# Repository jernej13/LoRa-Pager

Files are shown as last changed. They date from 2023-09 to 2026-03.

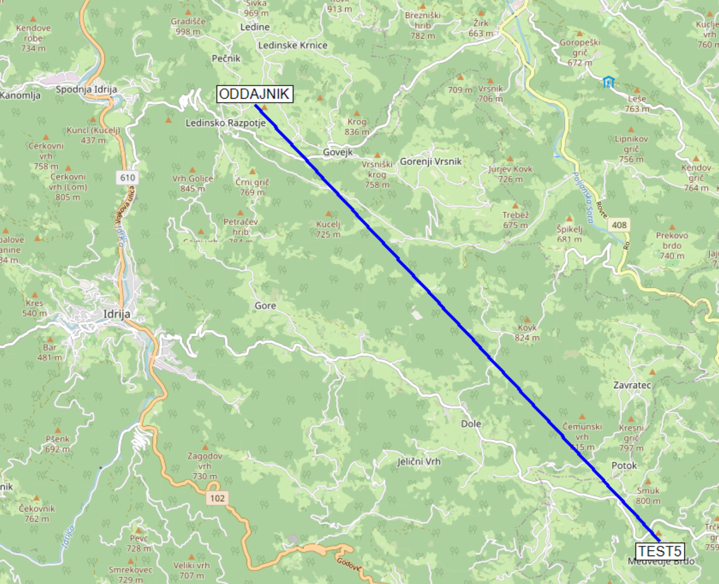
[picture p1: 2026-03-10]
tests/TEST5/map pic.png

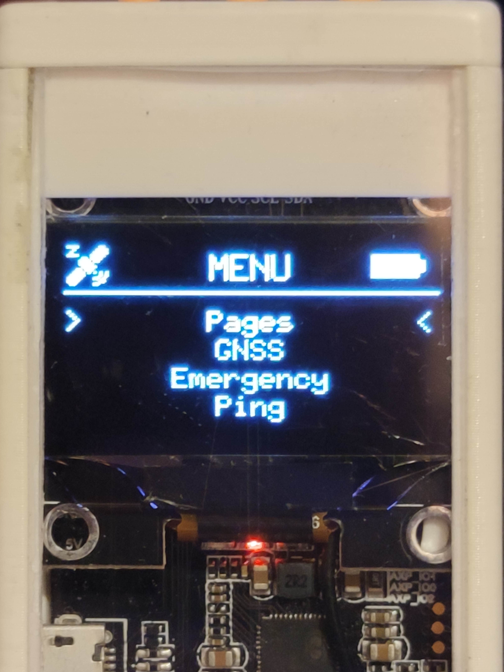
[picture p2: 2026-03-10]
pictures/IMG_20230325_204728.jpg

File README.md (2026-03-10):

# LoRa Pager (ESP32)

This repository contains my **high school graduation project (Slovenian *matura*)**, where I designed and built a **portable LoRa-based communication device** capable of long-range peer-to-peer messaging without relying on existing network infrastructure.

The device is built around an **ESP32 microcontroller** and uses **LoRa radio communication** to send predefined messages between devices over long distances.

The project includes **hardware design, embedded firmware, and a 3D printed enclosure**.

<p align="center">
  
</p>

---

## Features

* Long-range **LoRa peer-to-peer communication**
* **GNSS location support**
* **OLED graphical interface**
* Menu-based navigation with buttons
* **Emergency beacon mode**
* Battery monitoring and low-power operation
* Custom **3D printed enclosure**

---

## Hardware

Main components:

* ESP32 microcontroller
* Semtech **SX1276 LoRa transceiver**
* **U-blox NEO-M8N GNSS module**
* 128×64 **OLED display**
* Buttons and piezo buzzer
* Li-ion battery with power management

Development board used:

* **LilyGO TTGO T-Beam V1.1**

---

## Software

The firmware is written in **C++ using the Arduino framework** and developed with **PlatformIO**.

The program manages:

* LoRa communication
* GNSS data processing
* graphical user interface
* power management

---

## Results

Field tests achieved communication distances of **over 9 km** using LoRa with a transmission power of **0.1 W**.

---

## Author

**Jernej Leskovec**
High School Graduation Project (*Matura*)
Ljubljana, Slovenia

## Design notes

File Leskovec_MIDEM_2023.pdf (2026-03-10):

# LoRa Pager – Portable Off-Grid Communication

### Jernej Leskovec, Janez Omahen

The Upper Secondary School of Electrical and Computer Engineering
and Technical Gymnasium Ljubljana, Slovenia
jernej.leskovec13@gmail.com, janez.omahen@vegova.si

Abstract − This paper describes the selected parts, functionalities, and performance results of the LoRa pager prototype. LoRa pager is an off-grid peer-to-peer communicator that takes advantage of LoRa technology. The LoRa pager also uses the GNSS (global navigation satellite system) positioning to determine and send location.

### 1 INTRODUCTION

In our modern world, we increasingly rely on many different types of networks (cellular networks, internet). These come with trivial advantages, for example, high bitrates, good coverage, seamless connection, and low power consumption on the user end. But it also comes with some disadvantages: networks are localized and fragile. Even a power outage can lead a city or a whole region to lose modern communication with the rest of the world. In the case of a natural catastrophe, for example, a flood, the most
affected | parts | can | lose | all | network-related
connections. The only exceptions are radio amateurs who have expensive equipment and receive training. We wanted a more subtle, pocketable, and cheaper way of communicating long distances.

### 2 PARTS SELECTION

Searching the internet, we came across LoRa. LoRa is a somewhat new technology. It’s a way of communication using spread spectrum modulations, a branch of CSS (Chirp spread spectrum) technology. LoRa uses an open ISM (Industrial, scientific, medical) frequency band. There is no license needed for transmitting on 433 MHz (ISM) in Europe (that being if the transmission is using less than 25 mW of power) [1]. Next, we needed a microcontroller. ESP32 fits all the needs and is widely available. For the user interface, we decided on a small OLED screen with three buttons and a piezo speaker to go with it.

### 3 FUNCTIONALITY

The pager functions in a way that it sends integers instead of strings of data over the air, and every integer has a pre-programmed text to go with it. We choose a page in the menu, and when we send it, the LoRa module only sends the integer that belongs to that page. Next, the receiving LoRa module receives that integer, and the text allocated to that integer gets displayed on the display of the receiving pager. The advantages of this type of communication are lower battery consumption since we need less time to send that two-byte integer than the dozen-byte string packet, ease of use, and the unnecessity of a functional text input method. But this design also poses a couple of drawbacks, one of which is that we only have a selected number of pages to send, thus limiting the information we can tell.

### 3.1 User Interface

With such a small form factor and the lack of buttons to navigate the user interface, we have programmed the pagers to have a selection menu. We can navigate different options for the pager’s functionality in a menu. The menu has a layered setup, as seen in Figures 1 and 2.

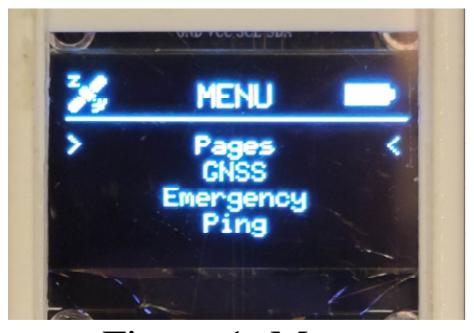
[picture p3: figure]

### 3.2 GNSS

The pager has a GNSS receiver since geolocation is practical in dire situations (Figure 3). We can send or receive the location from one pager to another. The pagers can also act as an emergency beacon, sending the position with an emergency page every 10 seconds (Figure 4).

Figure 1: Menu | Figure 2: Pages
Figure 3: GNSS Info | Figure 4: Receiving Emergency

### 4 HOUSING

The housing was 3D designed and 3D printed. It consists of 4 parts. The most significant is the main body, which has a hole for the USB micro connector. The bottom and the top part, the latter of which has four holes, three for buttons and the fourth one for the antenna. The fourth part is an acrylic glass that covers the front. The bottom and top were both screwed into place while the acrylic got glued (Figure 5).

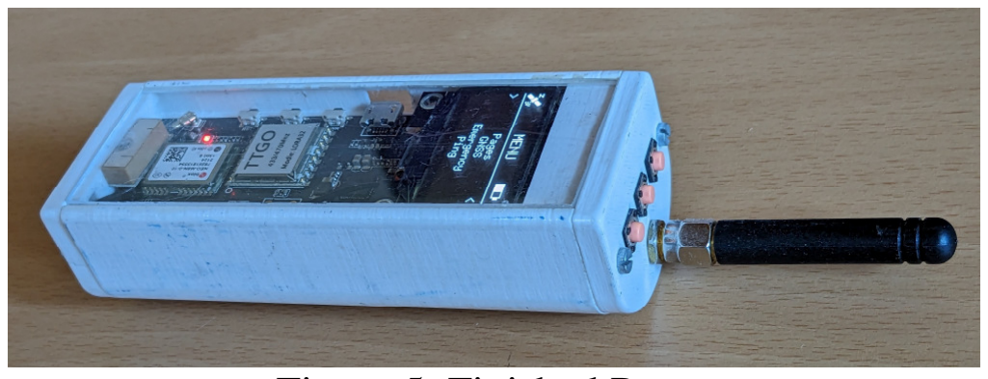
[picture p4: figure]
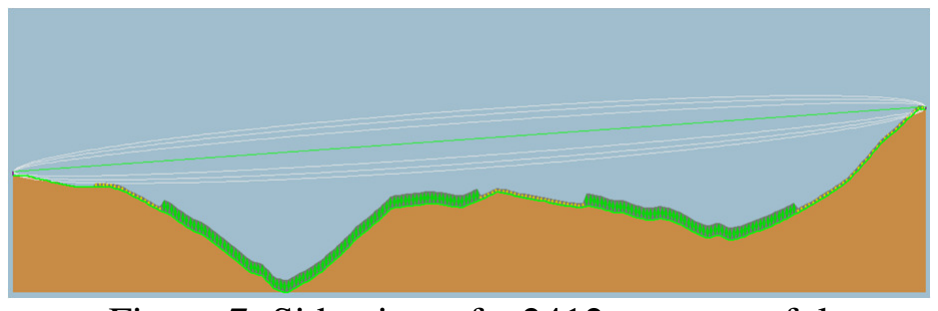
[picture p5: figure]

### 5 EXPECTATIONS

The world record for the LoRa transmission using 25 mW of power is 832 kilometers [2]. With that in mind, we were expecting a lot. Since 433 MHz is a high frequency and is very limited to the field of view, we expected our pagers would not work around big obstacles, such as hills or mountains.

### 6 RESULTS

We started testing the pagers with only the test code that pings one another. And at the beginning, the pagers were getting less than a hundred meters of range. The range increased after changing and calculating the best possible setting for LoRa. Testing the transmission range of the LoRa pagers if there is an obstacle in the way of the line of sight, has proven poorly. We had a transmitter that transmitted every 10 seconds about 200 meters away and 40 meters lower altitude from where we were standing on a small hill. The side facing the transmitter had reception, but we lost reception when we moved with our receiver just a few meters lower to the opposite side of the hill. After finishing the code for the pagers, we tested the range.

### 6.1 Short Distance

Short distance (~100m to ~2000m) line of sight pagers have no problem receiving. Signal strength (RSSI) ranges between -110 and -120 dBm. Trees, houses, and other small obstacles do not impact the signal strength.

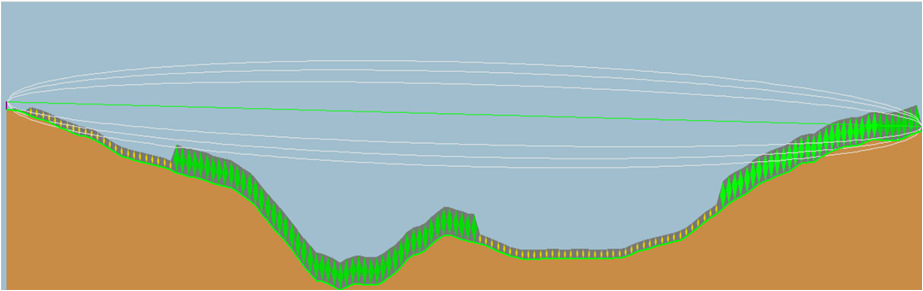
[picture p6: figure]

### 6.2 Long Distance

At longer distances (~2000m+) in line of sight, pagers have no problem receiving. RSSI is on the edge of pager capabilities, between -120 and -135 dBm. The estimated RSSI is -148 dBm [3], which is lower than what we managed to get, even when we barely received it. That RSSI would only be possible with the smallest bandwidth, but our pagers cannot handle anything below 62.5 kHz.

Figure 5: Finished Pager

Figure 6: Side view of a 1509m successful transmission (RSSI -116)

Figure 7: Side view of a 2412 m successful transmission (RSSI -114)

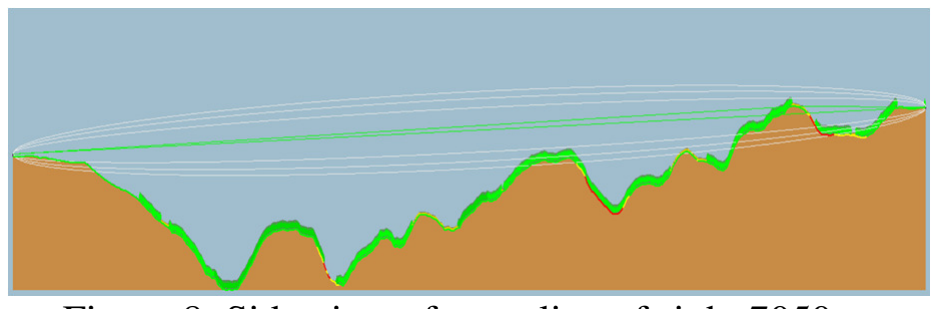
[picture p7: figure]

Figure 8: Side view of a not line of sight 7050 m successful transmission (RSSI -131)

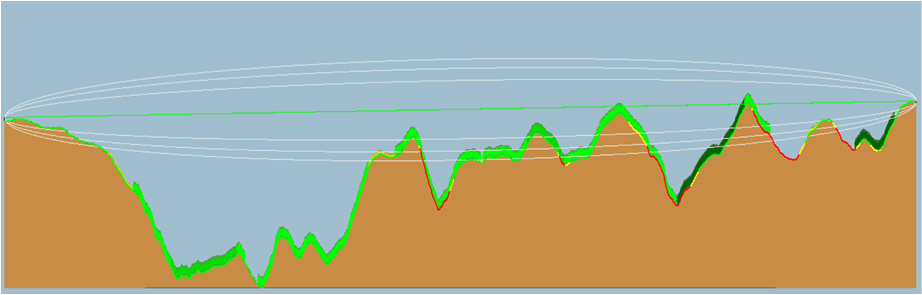
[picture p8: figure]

Figure 9: Side view of a 9231 m successful transmission (RSSI -132)

### 7 CONCLUSIONS

To sum up, we have built a portable, easy-to-use, and well-preforming off-grid communicator. The pagers have some advantages. For example, they can receive
through | small | obstacles | (houses, | trees) | and
communicate far distances in line of sight. Pagers also have decent battery performance since they can last (on a full charge) a week in receiving mode and a day in a mode transmitting every 10 seconds and with receiving GNSS.
The pagers also have disadvantages, a critical one being the inability to communicate through larger obstacles. Because of this disadvantage, the usefulness in hilly areas is limited. There is room for improvement by using an STM32 microcontroller, optimizing the code, and integrating a mesh communication system.

References

[1] “LoRa” Wikipedia,
https://en.wikipedia.org/wiki/LoRa, obtained: Aug 16th, 2023
[2] The Things Network
https://www.thethingsnetwork.org/article/lorawan -world-record-broken-twice-in-single-experiment-1, obtained: Aug. 16th, 2023
[3] SX1276/77/78/79 – 137 MHz to 1020 MHz
Low Power Long Range Transceiver,
Semtech Corporation, Rev.5 – August 2016, Authorized Distributor: Mouser Electronics https://www.mouser.com/datasheet/2/761/sx1276-1278113.pdf, obtained Aug 16th, 2023

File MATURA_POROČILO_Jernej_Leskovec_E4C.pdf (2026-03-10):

# LORA POZIVNIK

Strokovno poročilo

Mentor: Janez Omahen, prof. | Avtor: Jernej Leskovec, E 4. C

Ljubljana, marec 2023

POVZETEK

V tej maturitetni nalogi sem naredil napravo, ki lahko brez obstoječih omrežij doseže daljše

razdalje prenosa in je kljub temu dovolj majhna, da jo lahko pospravimo v žep. Vsem tem

zahtevam ustreza LoRa tehnologija. Poleg LoRe sem se odločil še za ESP32 mikrokrmilnik,

ker je kompatibilen in energijsko varčnejši. Kupil sem razvojno ploščico proizvajalca LilyGo,

ki ima že nameščen čip LoRa in ESP32, dodan ima pa še čip GNSS. Prispajkal sem OLED

prikazovalnik, tri tipke in piezo zvočnik. Nato sem napisal programsko kodo, ki upravlja z

vsemi moduli. V mislih, da ima LoRa počasen prenos podatkov, sem kodo napisal na princip

»pozivnika« in s tem znižal kvantiteto prenesenih podatkov, kar direktno vpliva na porabo

energije. Naslednje sem zmodeliral ohišje in ga natisnil na 3D tiskalnik. Na koncu sem

pozivnika še preizkušali, dosegla sta več kot devet kilometrov dolg prenos.

KLJUČNE BESEDE: LoRa, lokalna komunikacija, prenosljivost, 3D tiskanje, ESP32,

pozivnik

ABSTRACT

This project deals with developing a device, which is capable of peer-to-peer communication.

The aim is to achieve the longest possible transmission distance using as little energy as possible.

The device should be small enough to fit into anybody’s pocket. LoRa technology is selected

on the basis of parameters required and is paired with an ESP32 microcontroller. The latter is

easily available, compatible, and has a low energy consumption. Firstly, a prebuilt developer

kit from LilyGO, with on-board LoRa transceiver chip as well as a GNSS chip was acquired.

An OLED display, three buttons, and a piezo speaker were soldered. The code, which manages

all the modules was written. Considering LoRa’s slow data transfer, packets are sent using

“pages” to lower data transmission which directly affects time and power consumption. Next,

a case for the device was designed using 3D modelling and printed on a 3D printer. The tests

show a transmission length achieved is greater than nine kilometres.

KEY WORDS: LoRa, peer-to-peer, portability, 3D printing, ESP32, pager

Kazalo:

Kazalo slik

Slika 1: Blok shema pozivnika |
Slika 3: Programske knjižnice |
Slika 4: Del sistemskih deklaraciji |
Slika 5: Del začetne funkcije |
Slika 6: Prekinitveni funkciji |
Slika 7: Del glavne zanke |
Slika 8: Del GNSS razčlenitvene funkcije |
Slika 10: Prikazovanje GNSS podatkov, v primeru premikanja |
Slika 9: Prikazovanje GNSS podatkov, v primeru mirovanja |
Slika 11: Izračun smeri puščice pri GNSS prikazovalniku |
Slika 12: OLED prikaz sistemskih informaciji |
Slika 13: Prikaz nastavitev |
Slika 14: OLED prikaz menija |
Slika 15: Del data baze pozivov |
Slika 16: Pošiljanje pozivov |
Slika 17: Sprejemanje pozivov |
Slika 18: 3D model trupa |
Slika 19: Zemljevid prvega preizkusa |
Slika 20: Teren in pot signala prvega preizkusa |
Slika 22: Teren in pot signala drugega preizkusa |
Slika 21: Zemljevid drugega preizkusa |
Slika 24: Teren in pot tretjega preizkusa |
Slika 23: Zemljevid tretjega preizkusa |
Slika 25: Zemljevid četrtega preizkusa |
Slika 26: Teren in pot signala četrtega preizkusa |
Slika 27: Teren in pot signala petega preizkusa |
Slika 28: Zemljevid petega preizkusa |
Slika 29: Referenčna slika razdalje petega preizkusa |
Slika 30: Končani pozivniki |

Kazalo tabel

### 1. UVOD

Namen mojega izdelka je bilo narediti pozivnik, ki ni odvisen od že postavljenih omrežij (npr.

telefonskega) in ima sorazmerno dolg doseg. Ena glavnih uporab takega izdelka bi bilo

pošiljanje klicev v sili v kriznih situacijah, kjer ni dostopa do ostalih omrežij. Naprava mora

biti za opravljanje tovrstnih nalog lahka, prenosljiva in imeti dolgo baterijsko dobo. To uspe

doseči tehnologiji LoRa.

LoRa (Long Range) je tehnika radio prenosa informaciji, ki temelji na modulaciji razpršenega

spektra (ang. Spread spectrum modulation), ki izvira iz CSS (Chirp spread spectrum)

tehnologije. Iznašlo jo je podjetje Cycleo, ki ga je kasneje prevzelo podjetje Semtech.[1][2][3]

LoRa uporablja ISM (Industrial, scientific, medical) frekvenčno območje in zato v Evropi ne

potrebujem licence za oddajo.[4] LoRa ima imeniten doseg, ampak je zaradi uporabljenega

frekvenčnega spektra limitirana na vidno polje. Razdalje dosega lahko pod optimalnimi pogoji

dosežejo tudi do več sto kilometrov.[5]

ESP32 mikrokontroler je eden izmed najbolj kompatibilnih mikrokonotrolerjev z Arduino okoljem. Čip je precej močnejši in manjši od Arduino mikrokontrolerjev, ki smo jih uporabljali

pri pouku in ima tudi več funkciji in spomina. Ima funkcijo spanja, tako ne porablja nepotrebne

energije, kadar miruje.

### 2. METODOLOGIJA

Odločil sem se za mikrokontroler ESP32, proizvajalca Espressif Systems[6]. Zanj sem se

odločil zaradi široke izbire kompatibilnih knjižnic in količine spomina. Izbral sem si LoRa

modul proizvajalca Semtech. ESP32 in LoRa (Semtech SX1276) se nahajata na kupljeni

razvojni ploščici podjetja LilyGo, linije TTGO, model T-Beam V1.1. Vezje dodatno vsebuje

GNSS (globalni navigacijski satelitski sistem, ang. Global Navigation Satellite System) čip,

podjetja U-blox, linija NEO, model M8N. Za upravljanje sem prispajkal še tri tipke in piezo

zvočnik.

2.1 BLOK SHEMA

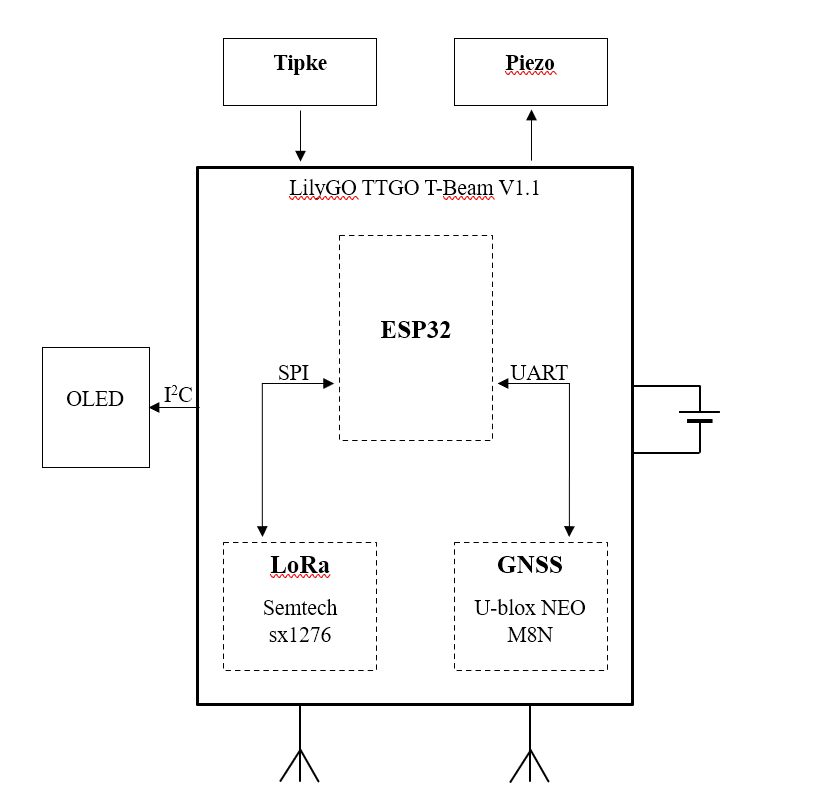
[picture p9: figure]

Blok shema predstavlja samo glavne komponente:

- Za vnos podatkov o navigaciji po meniju sem uporabil tri tipke, ki so na zgornji strani

ohišja in so povezane z ESP32,

- poleg tipk sem priključil tudi piezo zvočnik, ta je v ohišju, potreben je za opozarjanje o

sprejetih pozivih, povezan je na ESP32,

- ESP32 komunicira z LoRa čipom preko SPI komunikacije,

Slika 1: Blok shema pozivnika

- ESP32 komunicira z GNSS čipom preko zaporedne (UART) komunikacije,
- ESP32 pošilja podatke 64 x 128 OLED prikazovalniku preko I²C,
- na vezju je še modul za upravljanje z baterijo. (več: [7])

2.2 ELEKTRIČNA SHEMA

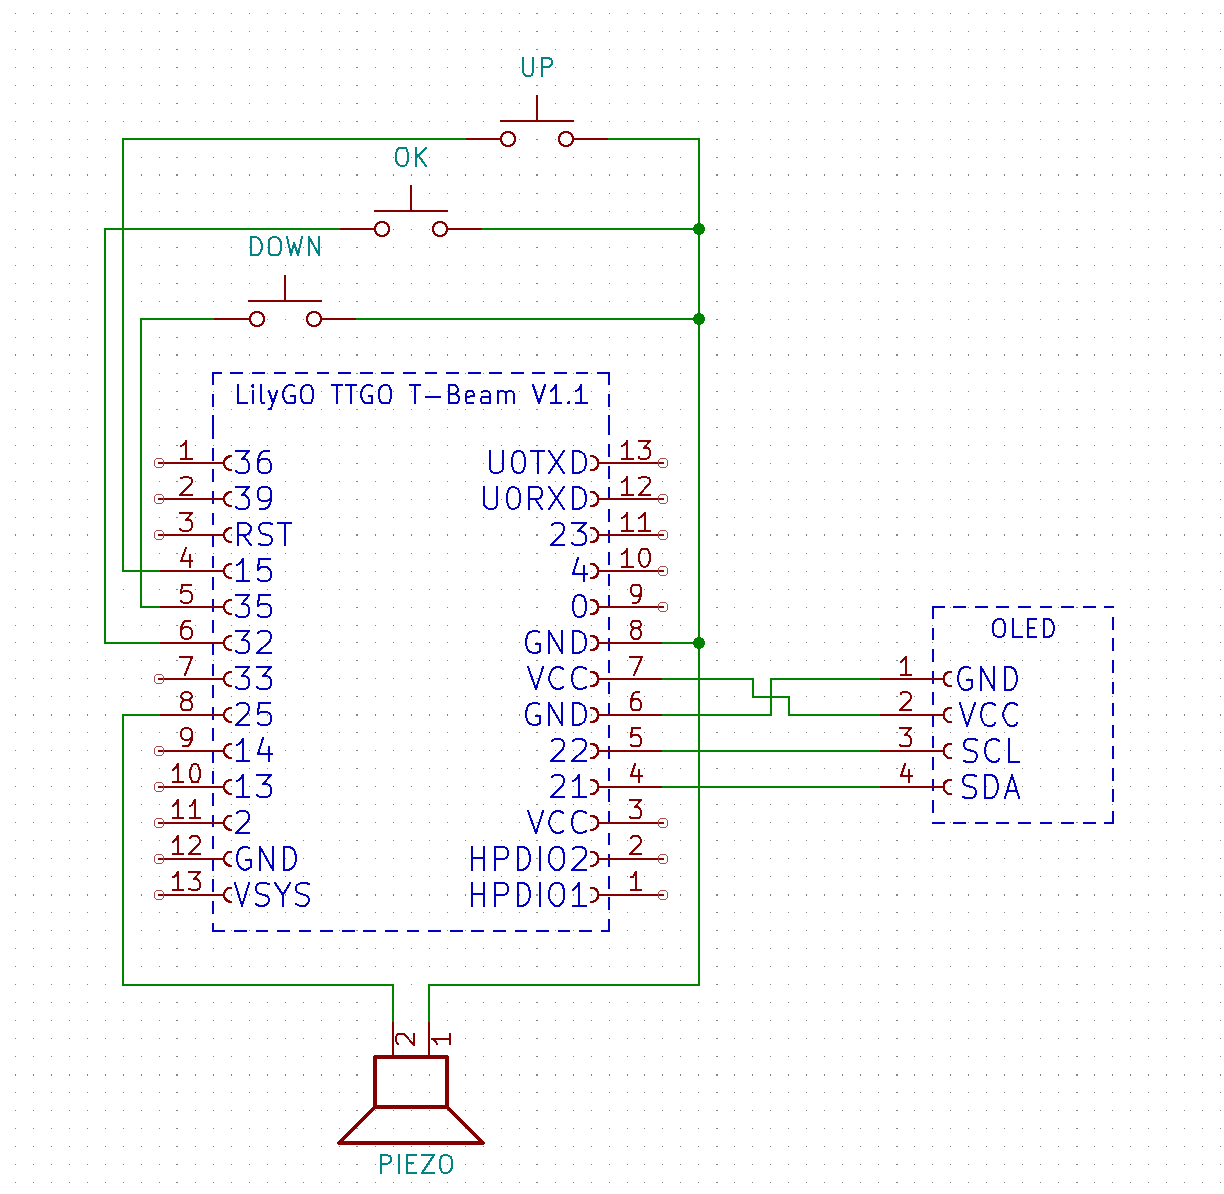
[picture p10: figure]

Slika 2: Električna shema pozivnika

Opombe električne sheme:

- Tipke nimajo »pull down« upora, ker je definiran v programu in posredno vezan v

samem mikrokontrolerju,

- električna shema [7] vezja LilyGO TTGO T-Beam V1.1 je priložena v prilogi,
- baterija je vezana že na samo vezje,
- povezave so narejene samo z žicami.

2.3 PROGRAMSKA KODA

Koda za ESP32 temelji na Arduino okolju, pisana v programu VSCodium (odprtokodna verzija

programa VSCode) z razširitvijo Platform.io. Zaradi nizkega prenosa podatkov sem sistem

pošiljanja podatkov in grafični vmesnik tako sprogramiral, da lahko na meniju izbiraš in tudi

pošiljaš različne pozive. Pozivi so zasnovani na vprašanju in odgovorih (npr. na vprašanje

»Where are You?« je odgovor »Heading North«). Koda ima še ostale uporabne funkcije, kot so

svetilnik v sili, GNSS grafični vmesnik, »ping« program (za preizkušanje obojestranske

povezave) in nastavitve.

### 2.3.1 Vpogled

Programsko kodo sestavljajo:

- 6 knjižnic,
- deklaracije spremenljivk in konstant,
- funkcija setup(), ki se izvrši samo enkrat na začetku programa,
- 2 prekinitveni funkciji,
- funkcija loop(), ki se izvaja kot zanka,
- 23 vmesnih funkciji, ki se izvršijo v funkciji loop().

Koda je napisana na način, da na koncu vsake izvedbe funkcije loop() ESP pade v lahko

spanje[8]. Zbudimo ga z dvema prekinitvenima (ang. interrupt) funkcijama, eno funkcijo izvede

pozitivni impulz na vhod 32, ki je vezan na sredinsko tipko(OK), za vstop v meni. Drugo

funkcijo izvrši prekinitvena funkcija, ki je vezana na klicni izhod LoRa čipa (ang.

callback)[7][9], za izpis sprejetega poziva.

Vse funkcije razen setup() in prekinitvenih funkciji se izvedejo v glavni zanki loop(). Zaradi

delovanja brez zapletov so v funkcijah zelo pogosto uporabljene while zanke in millis().

Funkcije delay() sem se izogibal, ker zniža zanesljivost programa.

Določenih odsekov kode ni slikanih v dokumentu zaradi omejitve s prostorom, zato vam v

prilogi prilagam celotno kodo.

(v. 10) pomeni 10 vrstica na slikah kode.

### 2.3.2 Knjižnice

V programu sem uporabil 6 knjižnic:

1. Knjižnica axp20x[10] za

upravljanje z nadzorom

napajanja in polnjenjem baterije.

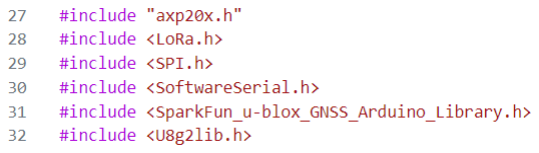
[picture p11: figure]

2. Knjižnica LoRa[11] za upravljanje z LoRa čipom, sprejemanjem in oddajanjem

pozivov.

3. Knjižnica SPI[12], Arduino knjižnica za SPI komunikacijo, ki je uporabljena za

komuniciranje z LoRa čipom.

4. Knjižnica SoftwareSerial[13] za zaporedno (UART) komunikacijo, ki se uporablja za

komuniciranje z čipom GNSS.

5. Knjižnica SparkFun u-blox GNSS Arduino Library[14] za upravljanje z čipom GNSS

in branje podatkov GNSS.

6. Knjižnica U8g2lib[15] za upravljanje z OLED prikazovalnikom.

### 2.3.3 Sistemske deklaracije

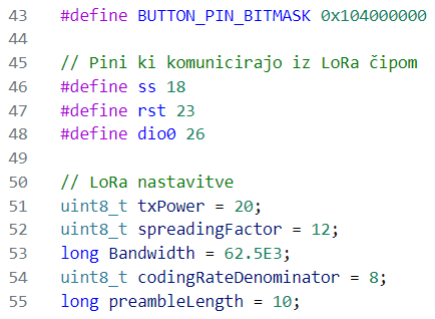
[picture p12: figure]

Deklaracije, ki so obvezne za delovanje sistema in

komunikacijo med vsemi moduli:

- Definicija (v. 43) definira vhode, ki bodo,

če bo na njih logična ena, zbudili ESP32 iz

spanja. Definicija je 10400000016, kar

pomeni vhod 26 in 32,

- deklaracije (v. 51 do 55) označujejo

nastavitve LoRa oddajnika in sprejemnika.

### 2.3.4 Globalne deklaracije in spremenljivke

2.3.4.1 Splošne

- Deklaracije spremenljivk (v. 74 do 77), ki so uporabljene pri sprejemanju pozivov,

MSG je označen poziv, RSSI pa moč sprejema poziva,

- deklaraciji spremenljivk (v. 80, 81), ki se uporabljata kot pomnilniški celici, sta ključni

za delovanje prekinitvenih funkciji,

- deklaracije spremenljivk (v. 96 do 103), ki se uporabljajo za zapisovanje in obdelavo

podatkov, prejetih od čipa GNSS.

Slika 3: Programske knjižnice

Slika 4: Del sistemskih deklaraciji

2.3.4.2 Grafični vmesnik

- Deklaracija spremenljivk (v. 111 do 146), ki so uporabljene za optimizacijo meni

kode,

- definicije in deklaracije (v. 154 do 188) za risanje dveh slik.

### 2.3.5 Začetna funkcija: setup()

Začetna funkcija, v Arduino okolju poimenovana setup(), je odgovorna za nastavitev in

inicializacijo. Izvrši se samo enkrat na začetku, ko smo mikrokontroler ali prižgali ali resetirali.

Funkcija v mojem primeru opravi naslednje pomembne naloge:

- Začne komunikacijo

z ostalimi moduli,

- nastavi vhode in

izhode LoRa čipa,

tipk in pieza,

- (v. 294 do 298)

pošlje nastavitve za

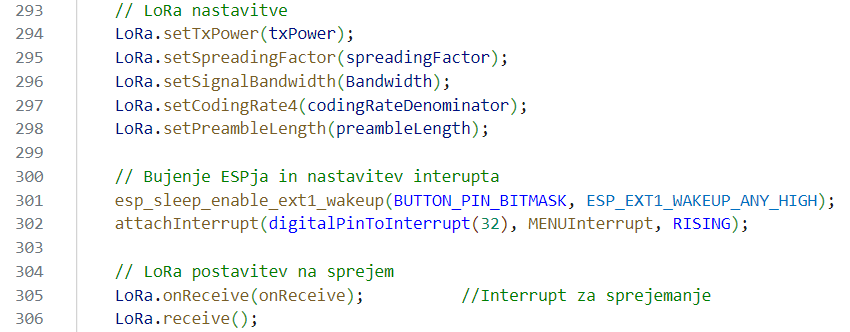
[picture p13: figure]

oddajo in sprejem LoRa čipu,

- (v. 301) ESP-ju nastavi vhode, ki ga bodo zbudili,
- (v. 302) ESP-ju nastavi vhod 32 za izvajanje prekinitvene funkcije za meni

(MENUInterrupt()),

- (v. 305) nastavi vhod 26, ki bo izvršil prekinitveno funkcijo onReceive() ob sprejemu

paketa,

- (v. 309) nastavi izpis čipa GNSS na samo UBX signale (Značilni za U-blox čipe) in

napiše konfiguracijo v register.

### 2.3.6 Prekinitvene funkcije

Prekinitvene funkcije (ang. interrupt) so funkcije, ki ob

določenih izpolnjenih pogojih ustavijo glavno zanko,

ne glede na njeno trenutno funkcijo, izvršijo ukaze v

prekinitveni funkciji in se vrnejo ter nadaljujejo glavno

zanko od tam, kjer so jo prekinile.

Slika 5: Del začetne funkcije

Slika 6: Prekinitveni funkciji

2.3.6.1 Sprejemna prekinitvena funkcija: onRecieve()

Funkcija, ki se izvrši, ko LoRa čip sprejme paket in izhod DIO0, ki je vezan na vhod 26, postavi

na logično 1.

2.3.6.2 Meni prekinitvena funkcija: MENUInterrupt()

Prekinitvena funkcija, ki je odgovorna, da zbudi ESP iz spanja in odpre meni. Zaradi zasnove

glavnega programa je dovolj, da v tej funkciji samo nastavimo »counter« pomnilno celico na 1.

### 2.3.7 Glavna zanka: loop()

Glavna zanka je odgovorna za

pregled, katera prekinitvena

funkcija je bila izvršena (preko

pomnilnih celic) in odvisno od

tega izvrši pravilno funkcijo. V

njej je vgrajen tudi izpis

sprejetih podatkov GNSS

(zaradi daljšega paketa in

optimizacije). Odgovorna je

tudi za uspavanje GNSS in čipa

ESP.

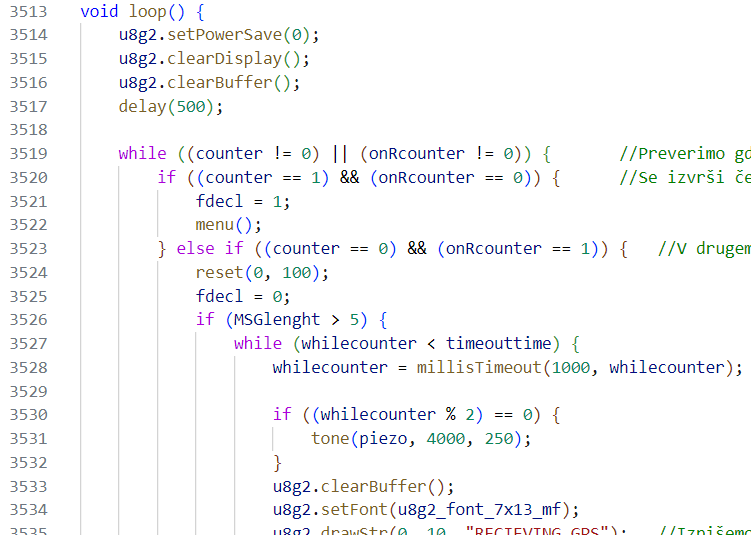
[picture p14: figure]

Na sliki desno vidimo kodo (v. 3520- 3523), ki predstavlja logiko za pravilno klicanje

funkciji, odvisno od prekinitvene funkcije, ki je bila izvedena.

- (v. 3561) Kličemo funkcijo, ki čip GNSS postavi v spanje,
- (v. 3565) kličemo funkcijo, ki čip ESP postavi v lahko spanje.

### 2.3.8 GNSS razčlenitvena funkcija: LoRa_GNSS_Parser()

Knjižnica za GNSS nam poda 4 podatke o lokaciji. Vsi trije podatki so zapisani kot dolgo

naravno število (ang. integer), zaradi tega moramo vse štiri podatke zapisati kot en niz. To

naredimo zato, da lahko pošljemo GNSS podatke v enem paketu in ne v štirih (zmanjšanje čas

oddaje in posredno porabo energije). To dosežemo s funkcijo sprintf(), ki zapakira 4 naravna

števila v en niz, tega pa nato pošljemo sprejemalcu. V primeru sprejemanja podatkov moramo

postopek ponoviti v obratni smeri s funkcijo sscanf(), ki nam poda 4 naravna števila. Naravna

števila nato spremenimo v 4 racionalna števila (float), primerna za zapis.

Slika 7: Del glavne zanke

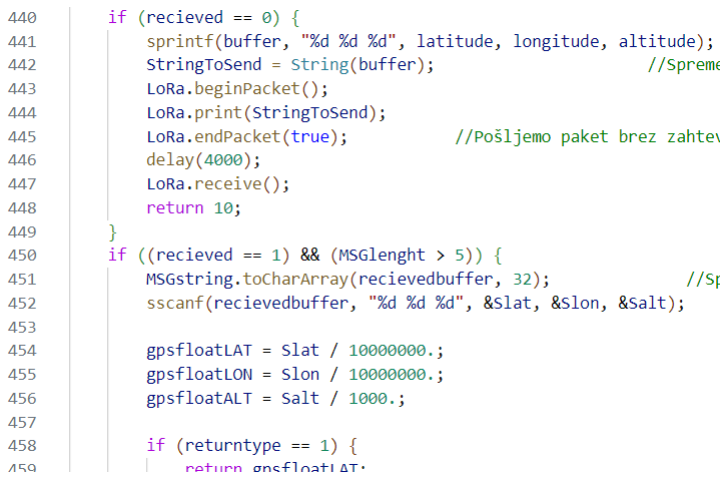
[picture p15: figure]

- Z »if« stavkom preverjamo ali

smo GNSS sprejeli, ali ga

bomo poslali,

- (v. 441, 442) funkcija sprintf()

podatke zapakira v zbirko,

katero nato pretvorimo niz,

- (v. 451, 456) pretvorimo

sprejeti niz v zbirko in nato jo

pretvorimo v racionalna

števila.

### 2.3.9 Funkcija za grafični vmesnik: level()

Funkcija, ki oblikuje in izpisuje vse v meniju. Omogoča nam izbiranje in premikanje med pozivi

in ostalimi funkcionalnostmi programa. Upravljamo jo s tipkami - leva tipka nas premika dol,

desna gor in sredinska naprej. Funkcija je ključna za optimizacijo kode, saj jo skrajša za najmanj

5000 vrstic.

- Najprej vsem nizom, ki jih bomo zapisali, določimo dolžino (za sredinsko poravnavo),
- nato izpišemo prvo stran menija,
- potem konstantno preverjamo, ali je tipka pritisnjena, in če je, se kazalec premakne,
- če imamo več opcij, se nadaljujejo še na drugi in tretji strani.

### 2.3.10 Svetilnik v sili: emergency_beacon()

Svetilnik v sili oddaja signal vsakih 10 sekund in istočasno išče GNSS satelite. Ko enkrat čip

fiksira lokacijo, jo začne oddajati. Funkcija, ki to sprejema (emergency_rec()), izpiše

sprejemanje in lokacijo GNSS na OLED prikazovalnik.

### 2.3.11 Funkcija: ping()

Funkcija za preizkušanje dvostranske povezave med pozivnikoma, najprej pošlje paket in nato čaka drugi pozivnik, ki paket sprejme in odda identičnega nazaj. Če je ping uspešen, funkcija

to izpiše na prikazovalnik poleg moči sprejema, v nasprotnem primeru pa izpiše, da ni uspešen.

Slika 8: Del GNSS razčlenitvene funkcije

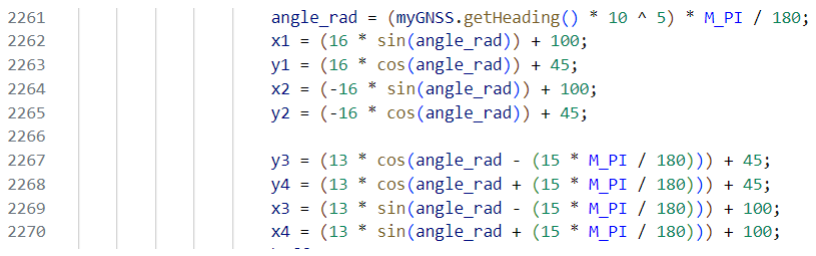
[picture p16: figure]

Slika 11: Izračun smeri puščice pri GNSS prikazovalniku

### 2.3.12 Prikazovalnik GNSS: GNSSinfo()

Funkcija prikazovalnik GNSS vklopi sprejemnik GNSS in čaka na njegove podatke. Ko se

GNSS fiksira, funkcija na OLED prikazovalnik izpiše sprejete podatke. Izpisani podatki so

zemljepisna širina, zemljepisna dolžina,

nadmorska višina, napaka v lokaciji, število

satelitov, s katerih sprejema podatke, hitrost.

Smer hitrosti je prikazana grafično. Izpiše

tudi čas in datum, ki sta shranjena v notranji

uri čipa GNSS.

- (v 2261 do 2270)

Enačbe za grafičen

prikaz smeri hitrosti.

### 2.3.13 Funkcija za prikaz sistemskih informaciji: sys_info()

Prikazane sistemske informacije se predvsem osredotočajo na baterijo in polnjenje. Funkcija

prikazuje trenutno napetost baterije, njen odstotek napolnjenosti, tok,s katerim se polni oziroma

prazni, koliko časa bo baterija še polna oziroma koliko časa se bo še polnila.

- Napetost na bateriji je podana v milivoltih,
- »T:« prikazuje čas, v katerem se baterija izprazni ob

trenutnih pogojih uporabe,

- »Ts:« prikazuje čas, v katerem bi se baterija izpraznila v

stanju spanja.

### 2.3.14 Funkcija za nastavitve: settings()

Nastavitve najdemo v meniju in nam omogočajo spreminjanje:

- GNSS nastavitev,
- LoRa nastavitev,
- čas izklopa,
- meni za izklop.

Slika 9: Prikazovanje GNSS podatkov, v primeru
premikanja

Slika 10: Prikazovanje GNSS podatkov, v primeru mirovanja

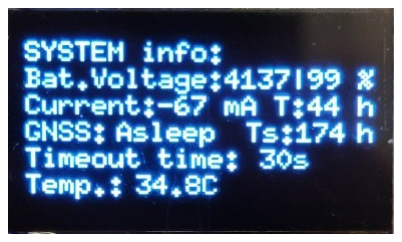
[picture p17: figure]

Slika 12: OLED prikaz sistemskih informaciji

Slika 13: Prikaz nastavitev

### 2.3.15 Meni funkcija: menu()

Meni funkcija služi izbiranju med pozivi in ostalimi funkcijami, ki

so naštete zgoraj. Funkcija level() prikazuje možnosti na OLED

prikazovalniku. Zaradi zasnove level() funkcije mi spreminjamo

samo deklaracije nizov, ki jih hočemo prikazati. Zbiranje deluje

preko »switch-case« stavka. Funkcija meni na prvi strani grafično

prikazuje tudi povezavo GNSS in vrednosti baterije.

### 2.3.16 Funkciji za pošiljanje in sprejemanje pozivov

2.3.16.1 Funkcija data baze vseh pozivov: pages()

Funkciji za pošiljanje in sprejemanje za delovanje

potrebujeta data bazo pozivov. Vsakemu pozivu pripada

ena številka, ki jo nato pošljemo sprejemalcu, ta mora za

pravilno delovanje imeti isto data bazo. Data baza in

grafični vmesnik v meniju sta lahko prilagodljiva,

pozivov je lahko tudi več tisoč. Data baza je zapisana v

obliki »switch case« stavka.

2.3.16.2 Funkcija za pošiljanje pozivov: menuPage()

Funkcija naprej izpiše poziv, ki ga hočemo poslati in ga pošlje, če

pritisnemo tipko.

2.3.16.3 Funkcija za sprejemanje pozivov: recievedPage()

Funkcija na OLED prikazovalniku izpiše poziv, ki smo ga sprejeli

in moč sprejema.

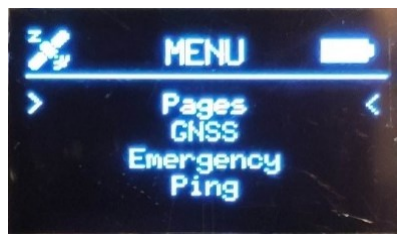
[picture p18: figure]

Slika 14: OLED prikaz menija

Slika 15: Del data baze pozivov

Slika 16: Pošiljanje pozivov

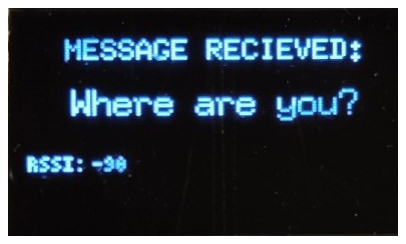
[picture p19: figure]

Slika 17: Sprejemanje pozivov

2.4 LORA NASTAVITVE

Do nastavitev in kako te vplivajo na dolžino dosega, čas in porabo sem prišel s pomočjo

programa od Semtecha[16], ki sem ga obratno inženiril (ang. reverse engineering) v MS Excelu.

To sem naredil zato, ker nikjer nisem našel enostavnih oziroma razumljivih enačb za nastavitve.

Nastavitve modulacije LoRa so ključne za doseganje dolgih razdalj prenosa[17]. Nastavitve, ki

pridejo v poštev pri doseganju daljših razdalj, so:

- moč oddaje (dB) določa, s kakšno močjo signal oddamo (polna moč je odvisna od

antene),

- razširitveni faktor določa čas trajanja čivka,
- pasovna širina (kHz) določa širino frekvenčnega pasu komunikacije.

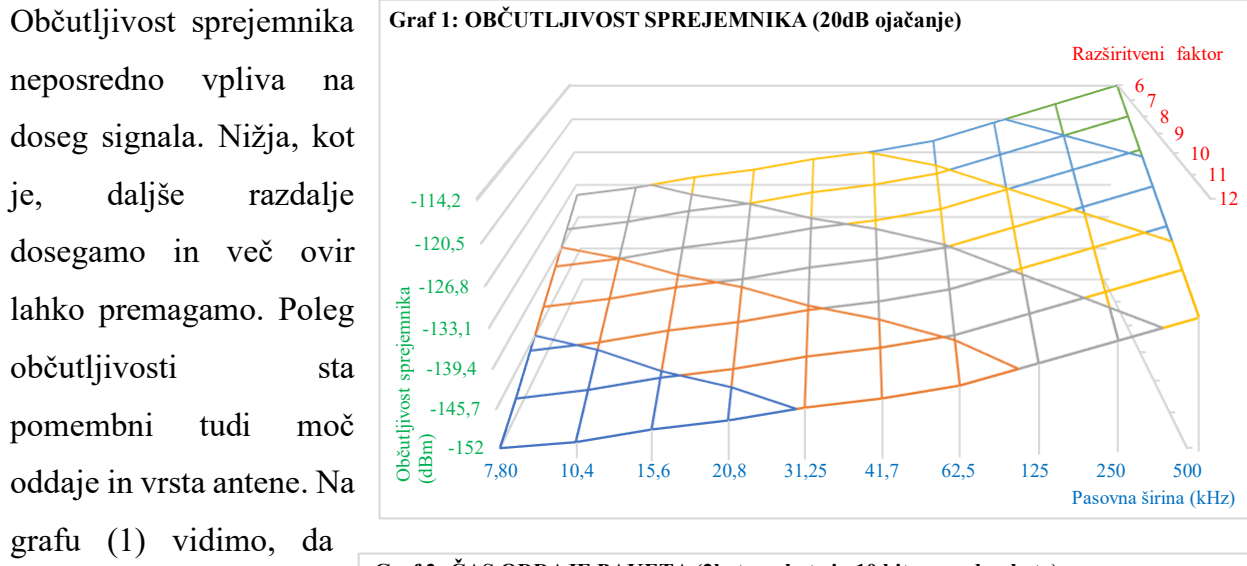
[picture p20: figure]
Občutljivost sprejemnika; neposredno; vpliva; doseg signala. Nižja, kot; daljše; razdalje; dosegamo in več ovir; lahko premagamo. Poleg; občutljivosti; sta; pomembni; tudi; moč; oddaje in vrsta antene. Na; grafu (1) vidimo, da; Razširitveni faktor; (dBm); Pasovna širina (kHz)

večji razširitveni faktor

in nižja pasovna dolžina

pri | istem | ojačenju

pripomoreta k najnižji

občutljivosti.

Čas oddaje (odvisen

tudi od dolžine paketa)

je poleg občutljivosti

sprejemnika | zelo

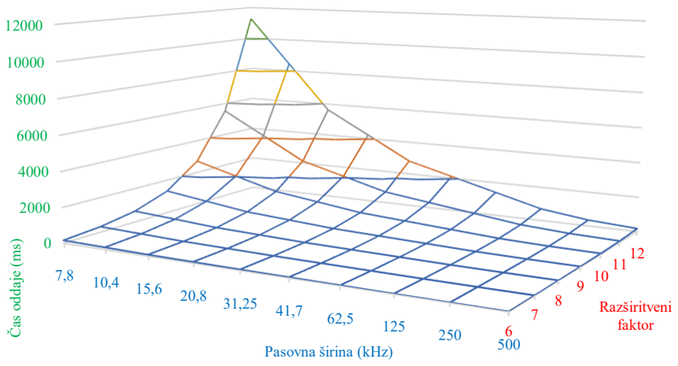
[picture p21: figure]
Razširitveni faktor; Čas oddaje (ms); Pasovna širina (kHz)

pomemben, ker je skupaj z močjo oddaje odgovoren za porabljeno energijo pri oddaji paketa.

Iz grafa (2) vidimo, da daljši doseg pomeni daljši čas oddaje in s tem tudi premosorazmerno

več porabljene energije.

Graf 2: ČAS ODDAJE PAKETA (2byta paketa in 10 bitov pred paketa)

Graf 1: OBČUTLJIVOST SPREJEMNIKA (20dB ojačanje)

V svoji konfiguraciji sem uporabil razširitveni faktor 12 v paru s pasovno širino 62,5 kHz

(zaradi neznanega vzroka, so se mi paketi nižjih pasovnih širin popačili, zato mi ni uspelo dobiti

najboljših rezultatov). Oddajal sem z močjo 20 dB (0,1 W). Ostale nastavitve sem imel

nastavljene na CR imenovalec 4/8 (pripomore v primeru motenj) in dolžino pred paketa 10

bitov. Dolžina paketa je 2 bajta, razen v primeru pošiljanja podatkov GNSS.

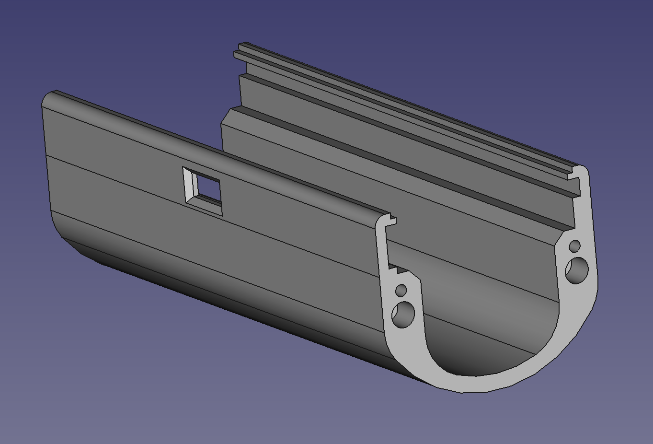
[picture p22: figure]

2.5 OHIŠJE

Ohišje sem načrtoval in zrisal v programu

FreeCAD in nato 3D natisnil na 3D

tiskalniku Prusa. Na sprednjo stran sem

nalepil 2 mm debelo akrilno steklo, saj sem

menil, da bo to izboljšalo videz. Vsi modeli

so priloženi.

### 2.5.1 Načrtovanje

Najprej sem s kljunastim merilom izmeril

vse mere in jih zapisal na papir, si na hitro skiciral in začel modelirati. Programske skice sem

načrtoval precej skromno, zaradi možnosti naknadnega popravljanja.

### 2.5.2 Modeliranje

Modelirati sem začel trup, nato pa še stranska pokrovčka. Imel sem več težav, ker sem prvič

uporabljal program in ga sproti spoznaval. Ko sem končal modeliranje, sem ohišje poskusil 3D

natisniti.

2.5.3 3D tiskanje

3D tiskanje celega ohišja je v povprečju trajalo od 3 do 4 ure. Ko se je natisnilo prvo ohišje, so

se začele pojavljati težave. Spoznal sem, da deli ne sedejo skupaj, tako kot sem načrtoval. Po

spremenjenem modelu sem ohišje ponovno natisnil, ampak se spet ni sestavilo po načrtih.

Tretjič sem se odločil, da bom začel od začetka. Po skoraj idealnem poskusnem tisku sem naredil samo še malo sprememb in dal tiskati. Čeprav sem prezrl majhno napako, sem natisnil

še ostali dve ohišji, in napako kasneje popravil s skalpelom. Natisnjena ohišja so bila iz belega

filamenta, zato sem se odločil, da bom dva od njiju prebarval z različnimi barvami. Pred

barvanjem sem jih zbrusil, saj sem hotel prikriti sledi 3D tiskanja. Dve ohišji sem prebarval in

medtem izrezal akrilna stekla, ki sem jih prilepil na sprednji del ohišja. Vrezal sem še vijačnice

in vse skupaj sestavil.

Slika 18: 3D model trupa

### 3. PREZIKUSI DOMETA

Po uspešnem sestavljanju in programiranju sem opravil 5 preizkusov. Preizkušal sem doseg

pozivnika v vidni liniji. Enega sem postavil na okensko polico in mu vključil funkcijo svetilnika

v sili. Z drugim sem preizkušal maksimalno razdaljo dosega. Izvajal sem jih v sorazmerno

gričevnatem terenu, kjer je bil kar izziv najti vidno linijo z oddajnikom. Rezultati so me

presenetili, saj nisem imel idealne kombinacije nastavitev. Preizkusi so bili izvedeni na isti dan,

med točkami sem se premikal z avtomobilom.

3.1 1. PREIZKUS

ODDAJNIK | TEST1
Zemljepisna širina | 46,031483 | 46,019708
Zemljepisna dolžina | 14,05466 | 14,044941
Nadmorska višina | 783m | 772m
Višina antene | 4m | 2m
Moč oddaje | 20dB
Pasovna širina | 62,5 kHz | 62,5 kHz
Razširitveni faktor | 12 | 12
DOLŽINA SPREJEMA: | | 1509m
MOČ SPREJEMA: (RSSI) | | -116 dBm

Tabela 1: Podatki prvega preizkusa

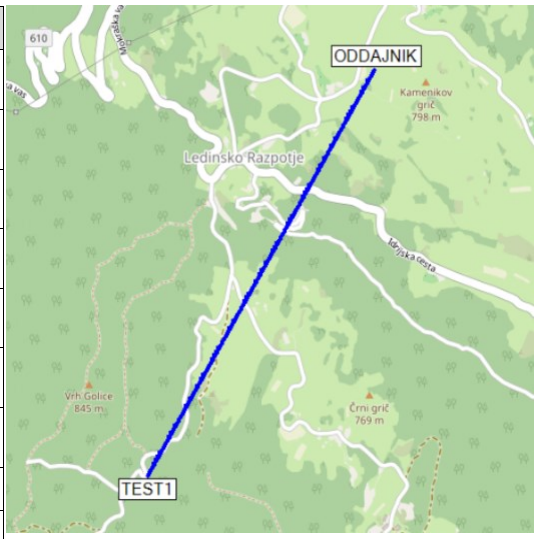
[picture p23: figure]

Slika 19: Zemljevid prvega preizkusa

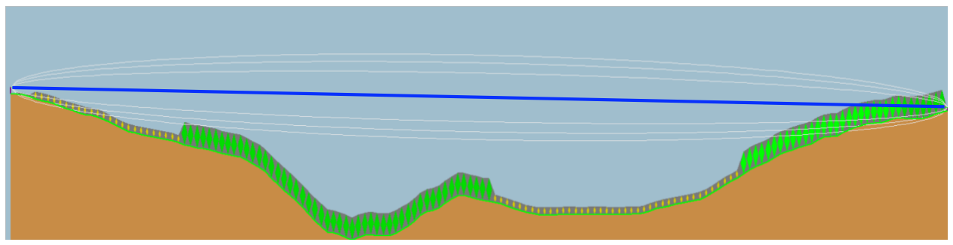
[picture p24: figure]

Slika 20: Teren in pot signala prvega preizkusa

3.2 2. PREIZKUS

ODDAJNIK | TEST2
Zemljepisna širina | 46,031483 | 46,016199
Zemljepisna dolžina | 14,05466 | 14,046049
Nadmorska višina | 783m | 806m
Višina antene | 4m | 2m
Moč oddaje | 20dB
Pasovna širina | 62,5 kHz | 62,5 kHz
Razširitveni faktor | 12 | 12
DOLŽINA SPREJEMA: | | 1825m
MOČ SPREJEMA: (RSSI) | | -113 dBm

Tabela 2: Podatki drugega preizkusa

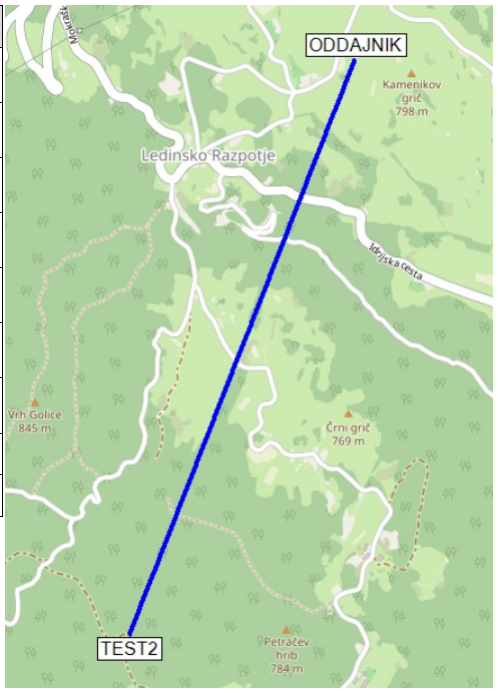
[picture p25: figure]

Slika 22: Zemljevid drugega preizkusa

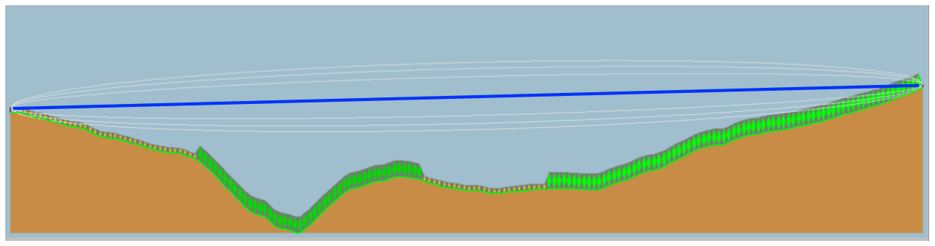
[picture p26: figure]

Slika 21: Teren in pot signala drugega preizkusa

3.3 3. PREIZKUS

ODDAJNIK | TEST3
Zemljepisna širina | 46,031483 | 46,009801
Zemljepisna dolžina | 14,05466 | 14,055484
Nadmorska višina | 783m | 864m
Višina antene | 4m | 2m
Moč oddaje | 20dB
Pasovna širina | 62,5 kHz | 62,5 kHz
Razširitveni faktor | 12 | 12
DOLŽINA SPREJEMA: | | 2412m
MOČ SPREJEMA: (RSSI) | | -114 dBm

Tabela 3: Podatki tretjega preizkusa


Slika 24: Zemljevid tretjega preizkusa


Slika 23: Teren in pot tretjega preizkusa

3.4 4. PREIZKUS

ODDAJNIK | TEST4
Zemljepisna širina | 46,031483 | 45,981353
Zemljepisna dolžina | 14,05466 | 14,110538
Nadmorska višina | 783m | 859m
Višina antene | 4m | 2m
Moč oddaje | 20dB
Pasovna širina | 62,5 kHz | 62,5 kHz
Razširitveni faktor | 12 | 12
DOLŽINA SPREJEMA: | | 7050m
MOČ SPREJEMA: (RSSI) | | -131 dBm

Tabela 4: Podatki četrtega preizkusa


Slika 25: Zemljevid četrtega preizkusa


Slika 26: Teren in pot signala četrtega preizkusa


Slika 27: Teren in pot signala petega preizkusa

3.5 5. PREIZKUS

Zemljepisna širina | Zemljepisna dolžina | Nadmorska višina | Višina antene | Moč oddaje | Pasovna širina | Razširitveni faktor
ODDAJNIK | 46,031483 | 14,05466 | 783m | 4m | 20dB | 62,5 kHz | 12
TEST5 | 45,970606 | 14,135921 | 808m | 2m | | 62,5 kHz | 12
DOLŽINA SPREJEMA: | | 9231m | MOČ SPREJEMA: (RSSI) | | | | -132

Tabela 5: Podatki petega preizkusa

Slika 29: Referenčna slika razdalje petega preizkusa

Slika 28: Zemljevid petega preizkusa

Vse preizkuse sem opravljal na isti lokaciji, zato so zemljepisna širina in dolžina ter nadmorska

višina enake. Prav tako se niso spreminjali parametri, kot so širina antene, moč oddaje in

pasovna širina. Pri prvem preizkusu je bila razdalja med sprejemnikom in oddajnikom najkrajša,

in sicer 1509 m, moč sprejema pa pri -116 dBm najboljša. Pri drugem preizkusu je bila pri

1825 m razdalje moč sprejema -113 dBm, pri tretjem preizkusu pa pri razdalji 2412 m, moč

sprejema -114 dBm. Ti trije preizkusi so pokazali najboljše rezultate, kar sem tudi pričakoval, saj razdalja ni bila prevelika in je bil oddajnik v vidnem polju sprejemnika. Četrti preizkus za

razliko od prejšnjih treh ni bil v vidnem polju, tudi razdalja je bila večja, in sicer 7050 m.

Rezultat me je presenetil, ker oddajnik ni bil v vidnem polju, zato sprejema signala nisem

pričakoval. Je pa v skladu s tem bila moč signala manjša, in sicer -131 dBm. Sprejem petega

preizkusa tudi ni bil pričakovan, ker nisem uporabljal idealnih LoRa nastavitev in sem

pričakoval slabše rezultate na daljše razdalje, v tem primeru 9231 m. Moč signala je bila tukaj

najnižja, -132 dBm, ampak vseeno ostaja še 10 dBm do teoretične meje sprejema.

### 4. ZAKLJUČEK

Cilj maturitetne naloge je bil dokončan izdelek, ampak sem od nje odnesel precej več. Bolj

podrobneje sem spoznal tehnologijo LoRa in ESP32 krmilnik, kako moduli med sabo

komunicirajo in delovanje sprejemnika GNSS. Najbolj pa sem izboljšal svoje znanje C++

programskega jezika in potrpežljivost, ki je potrebna za reševanje programskih izzivov. Uspelo

mi je narediti delujoč izdelek, ki z močjo 0.1 W dosega tudi do 10 km dosega. Ima grafični

vmesnik in funkcionalno kodo z več kot stotimi pozivi. Pozivnik ima na sprejemu porabo pod

16 mA, kar pomeni, da zdrži s trenutnimi baterijami en teden brez polnjenja.

Kljub temu da ima naprava dolg doseg, nisem prišel niti blizu polne sposobnosti LoRa

tehnologije. Prvič, uporabljal sem nastavitve, ki niso bile idealne za doseganje najdaljših

razdalji komunikacije, tudi antena, ki sem jo uporabljal, je bila dolga samo približno 5 cm, za

daljše povezave bi moral uporabljati 15 ali več centimetrsko anteno.

Izboljšava, ki mi je ni uspelo doseči, je vodotesno ohišje, podcenjeval sem že izdelavo

normalnega ohišja. Izdelek bi lahko bil nadgrajen na več možnih načinov, eden izmed njih je

izboljšati | kodo, | predvsem | odpravo

nepravilnosti in napak. Program se večkrat

zatakne in ga je treba resetirati, vzrok hroščev

je trenutno še neznan. Naslednja izboljšava bi

lahko bila povezava na satelite preko

tehnologije TinyGS[18], in tako povečanje

teoretičnega dosega komunikatorja do več

tisoč | kilometrov. | Z | zamenjavo | ESP32

mikrokontrolerja z mikrokontrolerjem STM bi

pridobili nižjo porabo in večjo učinkovitost. Število načinov, kako izboljšati ta projekt,

limitira proti neskončnosti, saj je tehnologija

uporabe nizke porabe za dolge komunikacije

zelo obetavna. Tudi sam se bom še v prihodnje

še ukvarjal s svojim projektom in njegovo

nadgradnjo.


Slika 30: Končani pozivniki

### 5. VIRI

[1] https://www.semtech.com/lora/what-is-lora (23. 3. 2023)
[2] https://web.archive.org/web/20190718200516/https://www.semtech.com/uploads/docu

ments/an1200.22.pdf (https://web.archive.org/web/20190718200516/https:/www.semtech.com/uploads/documents/an1200.22.pdf) (23. 3. 2023)

[3] https://www.design-reuse.com/news/28706/semtech-cycleo-acquisition.html (23. 3.

2023)

[4] 2021 LoRa Alliance https://lora-alliance.org/wp-content/uploads/2021/05/RP-2-

1.0.3.pdf (https://lora-alliance.org/wp-content/uploads/2021/05/RP-2-1.0.3.pdf) (24. 3. 2023)

[5] LoRa Alliance https://lora-alliance.org/lorawan-news/lorawanr-distance-world-record-

broken-twice-766-km-476-miles-using-25mw-transmission/ (https://lora-alliance.org/lorawan-news/lorawanr-distance-world-record-broken-twice-766-km-476-miles-using-25mw-transmission/) (24. 3. 2023)

[6] 2023 Espressif Systems

https://www.espressif.com/sites/default/files/documentation/esp32_datasheet_en.pdf

(24. 3. 2023)
[7] Xinyuan-LilyGO https://github.com/Xinyuan-LilyGO/LilyGo-LoRa-

Series/blob/master/schematic/LilyGo_TBeam_V1.1.pdf (https://github.com/Xinyuan-LilyGO/LilyGo-LoRa-Series/blob/master/schematic/LilyGo_TBeam_V1.1.pdf) (25. 3. 2023)

[8] 2016 – 2023 Espressif Systems https://docs.espressif.com/projects/esp-

idf/en/latest/esp32/api-reference/system/sleep_modes.html (https://docs.espressif.com/projects/esp-idf/en/latest/esp32/api-reference/system/sleep_modes.html) (25. 3. 2023)

[9] Sandeepmisty https://github.com/sandeepmistry/arduino-

LoRa/blob/master/examples/LoRaReceiverCallback/LoRaReceiverCallback.ino (https://github.com/sandeepmistry/arduino-LoRa/blob/master/examples/LoRaReceiverCallback/LoRaReceiverCallback.ino)

(25. 3. 2023)
[10] Lyusupov

https://github.com/lyusupov/SoftRF/tree/master/software/firmware/source/libraries/A

XP202X_Library (https://github.com/lyusupov/SoftRF/tree/master/software/firmware/source/libraries/AXP202X_Library) (25. 3. 2023)

[11] Sandeepmisty https://github.com/sandeepmistry/arduino-LoRa (25. 3. 2023)
[12] Arduino https://github.com/arduino/ArduinoCore-avr/tree/master/libraries/SPI
(25. 3. 2023)
[13] Plerup https://github.com/plerup/espsoftwareserial (25. 3. 2023)
[14] Sparkfun https://github.com/sparkfun/SparkFun_u-blox_GNSS_Arduino_Library
(25. 3. 2023)
[15] Olikraus https://github.com/olikraus/u8g2 (25. 3. 2023)
[16] https://sx1272-lora-calculator.software.informer.com/download/?cadc549 (25. 3.

2023)

[17] Martin Bor, Utz Roedig. 2017. School of Computing & Communications Lancaster

University. LoRa Transmission Parameter Selection. Dostopno prek:

https://eprints.lancs.ac.uk/id/eprint/85515/4/lora_tps_r1342.pdf (28. 3. 2023)

[18] 2023 TinyGS https://tinygs.com/ (28. 3. 2023)

### 6. PRILOGE

1. Priloga: MATURA_POROČILO_Jernej_Leskovec_E4C_PROGRAMSKAKODA.cpp
2. Priloga: LilyGo_TBeam_V1.1.pdf
3. Priloga: MATURA_POROČILO_Jernej_Leskovec_E4C_3DMODEL_OHIŠJE.FCStd
4. Priloga:
MATURA_POROČILO_Jernej_Leskovec_E4C_3DMODEL_POKROVCEK2.FCStd
5. Priloga:
MATURA_POROČILO_Jernej_Leskovec_E4C_3DMODEL_POKROVCEK1.FCStd

Izjava o avtorstvu

Izjavljam, da je strokovno poročilo Lora pozivnik v celoti moje avtorsko delo, ki sem ga izdelal

samostojno s pomočjo navedene literature in pod vodstvom mentorja.

Ljubljana, 30. 3. 2023 | Jernej Leskovec,

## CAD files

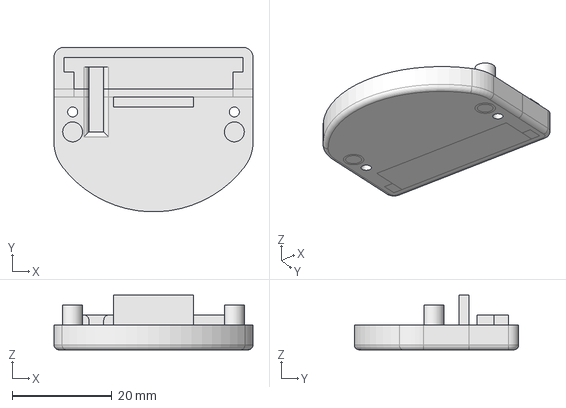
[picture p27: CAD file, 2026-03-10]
3d-files/MATURA_POROČILO_Jernej_Leskovec_E4C_3DMODEL_POKROVCEK2.FCStd
40.0 x 33.0 x 11.0 mm

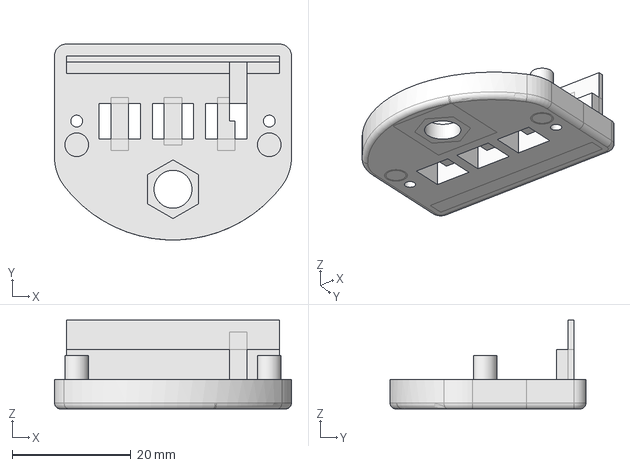
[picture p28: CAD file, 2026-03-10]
3d-files/MATURA_POROČILO_Jernej_Leskovec_E4C_3DMODEL_POKROVCEK1.FCStd
40.0 x 33.1 x 15.0 mm

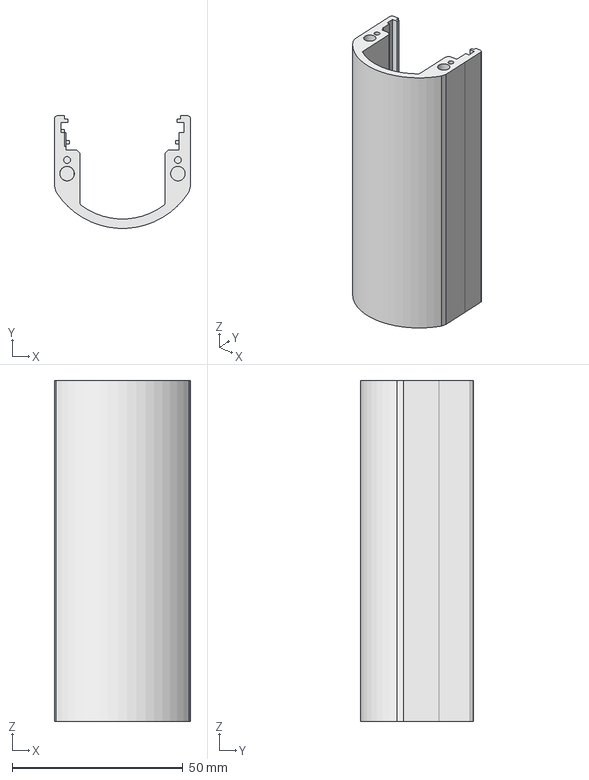
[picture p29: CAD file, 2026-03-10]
3d-files/MATURA_POROČILO_Jernej_Leskovec_E4C_3DMODEL_OHIŠJE.FCStd
40.0 x 33.0 x 100.0 mm

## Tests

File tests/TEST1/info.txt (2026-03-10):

ODDAJNIK:
Lat 46.031483
Lon 14.054660
Alt 783m
Antenna h. 4m
TX power 20dBm (0.1W)

TEST 1:
Lat 46.019708
Lon 14.044941
Alt 772
Antenna h. 2m
RX RSSI: -116

GENERAL:
distance: 1509m
freq: 433mHz

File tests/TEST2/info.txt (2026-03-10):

ODDAJNIK:
Lat 46.031483
Lon 14.054660
Alt 783m
Antena h. 4m
TX 20dBm

TEST2:
Lon 46.016199
Lat 14.046049
Alt 806m
Antena h. 2m
RX RSSI: -113

GENERAL:
Distance: 1,825 km
freq: 433

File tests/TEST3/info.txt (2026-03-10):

ODDAJNIK:
Lat 46.031483
Lon 14.054660
Alt 783m
Antena h. 4m
TX 20dBm

TEST3:
Lat 46.009801
Lon 14.055484
ALt 864m
Antena h. 2m
RX RSSI: -114

GLOBAL:
Distance 2,412 km
freq: 433mHz

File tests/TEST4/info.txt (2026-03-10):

ODDAJNIK:
Lat 46.031483
Lon 14.054660
Alt 783m
Antena h. 4m
TX 20dBm

TEST4:
Lat 45.981353
Lon 14.110538
Alt 859m
Antena h. 2m
RX RSSI: -131

GLOBAL:
distance 7,050 km
freq: 433

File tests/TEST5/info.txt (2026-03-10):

ODDAJNIK:
Lat 46.031483
Lon 14.054660
Alt 783m
Antena h. 4m
TX 20dBm
TX2 10dBm

TEST5:
Lat 45.970606
Lon 14.135921
Alt 808m
Antena h. 2m
RX RSSI: -132
RX2 RSSI: -137

GLOBAL:
distance: 9,231	km
freq: 433mHz

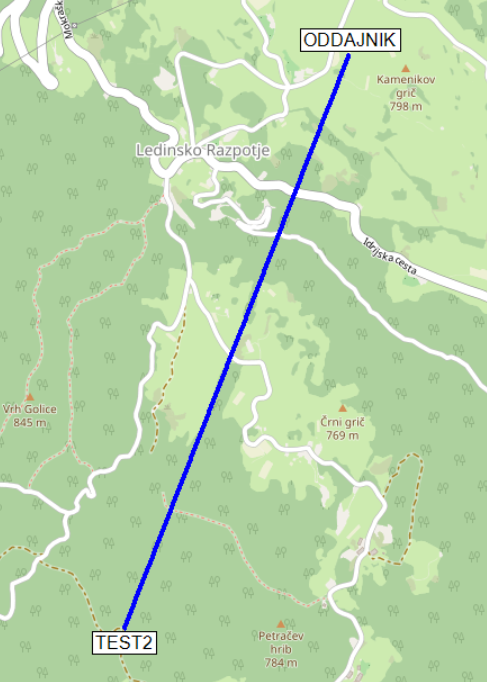
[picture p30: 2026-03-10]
tests/TEST2/map pic.png

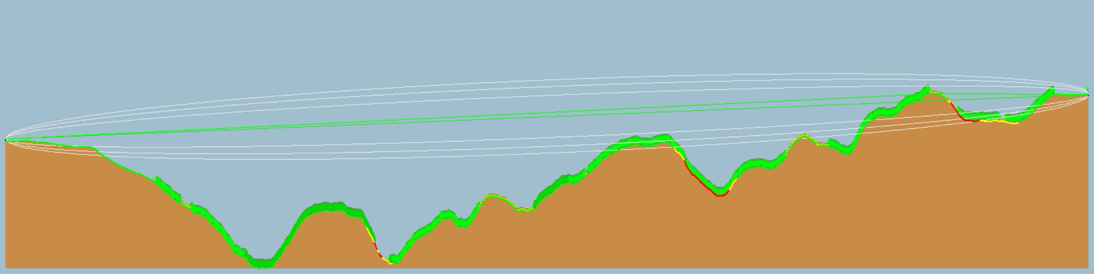
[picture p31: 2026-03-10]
tests/TEST4/link pic.png

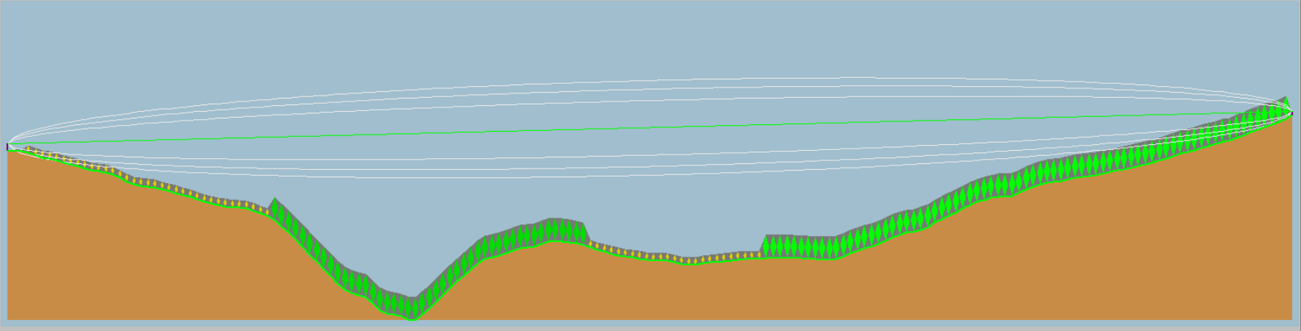
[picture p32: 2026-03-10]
tests/TEST2/link pic.png

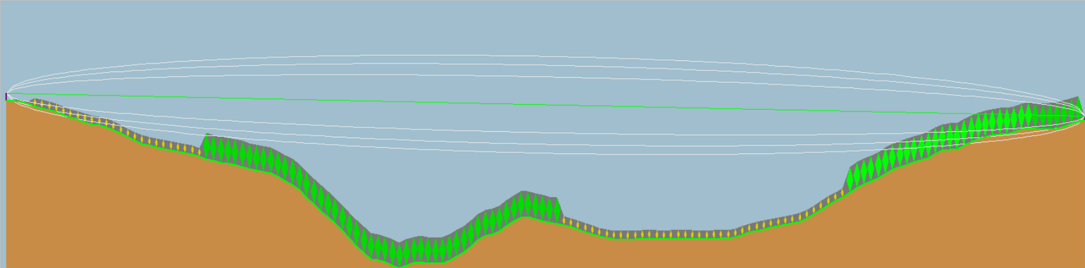
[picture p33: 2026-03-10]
tests/TEST1/link pic.png

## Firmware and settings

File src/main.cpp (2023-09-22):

/* MATURITETNA NALOGA
ELEKTROTEHNIŠKO-RAČUNALNIŠKA STROKOVNA ŠOLA IN GIMNAZIJA LJUBLJANA

Mentor: Janez Omahen, prof.
Avtor: Jernej Leskovec, E 4. B
Ljubljana, marec 2023

>>> LORA POZIVNIK <<<

Programska koda je napisana za ploščico LilyGO TTGO T-Beam. Na headerje 15, 35, 32
so vezane tipke, na 25 je vezan piezo zvočnik in na 22 in 21 je vezan OLED display.
Dodana je še 18650 baterija kapacitete okoli 2700 mAh. Koda ima več napak in se
večkrat zatakne, nevem še zakaj in kje, tako da je potrebno odpravljanje hroščev .

Knjižnice v celoti pripadajo njihovima avtorjem in se ne zavezam, da so moje
avtorsko delo. Koda spodaje je pa v celoti moje avtorsko delo, kodo lahko uporabljate
v kakršne koli namene in nisem odgovoren za poškodbe vezji itd.

(Koda je mišlena kot priloga poročilu maturitetnega izdelka.)

*/



/*KNJIŽNICE    
*/
#include "axp20x.h"
#include <LoRa.h>
#include <SPI.h>
#include <SoftwareSerial.h>
#include <SparkFun_u-blox_GNSS_Arduino_Library.h>
#include <U8g2lib.h>

/*SISTEMSKE DEKLARACIJE
    Deklaracije uporabljene za delovanje sistema.
*/

/* Maska za določanje pinov na ESPju ki ga bodo budile iz spanja
maska binarno je pozitivna samo na pinih, ki bodo zbudile ESP iz spanja
desna je 0; 1000 0010 0000 0000 0000 0000 0000 0000
*/

#define BUTTON_PIN_BITMASK 0x104000000

// Pini ki komunicirajo iz LoRa čipom
#define ss 18
#define rst 23
#define dio0 26

// LoRa nastavitve
uint8_t txPower = 2;
uint8_t spreadingFactor = 12;
long Bandwidth = 62.5E3;
uint8_t codingRateDenominator = 8;
long preambleLength = 10;

// Naslov ekrana
U8G2_SH1106_128X64_NONAME_F_HW_I2C u8g2(U8G2_R0, U8X8_PIN_NONE);    //prekliks za OLED

// Klasa in pini za komunikacijo iz čipom ki upravlja napajanje
AXP20X_Class axp;
const uint8_t i2c_sda = 21;
const uint8_t i2c_scl = 22;
const uint8_t slave_address = AXP192_SLAVE_ADDRESS;     //nastavimo i2c naslov

// Pini in klasa za upravljanja iz GNSSom
SoftwareSerial mySerial(34, 12);
SFE_UBLOX_GNSS myGNSS;                  //nastavimo prekliks za GNSS

/*GLOBALNE DEKLARACIJE IN SPREMENLJIVKE
    Obstajajo za ključno, lažje delovanje programa in simplifikacijo.
*/
// LoRa sprejem:
String MSGstring = "0";
uint32_t MSG = 0;
int16_t RSSI = 0;
uint8_t MSGlenght = 0;

// Za interrupte:
bool counter = 0;
bool onRcounter = 0;

// Števci za izklapljanje:
uint8_t whilecounter = 0;
uint16_t timeouttime = 30; // s
unsigned long previousTime = 0;
unsigned long previousTime1 = 0;
unsigned long previousTime2 = 0;

// Inputi in outputi espja
const uint8_t tipka1pin = 15;
const uint8_t tipka3pin = 33;
const uint8_t piezo = 25;

// Spremenljivke za GNSS
long gnssLAT = 0;
long gnssLON = 0;
long gnssALT = 0;
uint8_t SIV = 0;
int32_t ACC = 0;
int32_t Speed = 0;
bool GNSSisOFF = 0;
uint8_t GNSSsleepSETTIING = 0;

// Spremenljivke za napajanje
float batteryPercantage = 0;
float batteryMV = 0;

// Globalne spremenljivke, ampak uporabljene za oled
// Stringi za tekst v menuju
String TITLE;
String Screen1Row1;
String Screen1Row2;
String Screen1Row3;
String Screen1Row4;
String Screen2Row1;
String Screen2Row2;
String Screen2Row3;
String Screen2Row4;
String Screen2Row5;
String Screen2Row6;
String Screen3Row1;
String Screen3Row2;
String Screen3Row3;
String Screen3Row4;
String Screen3Row5;
String Screen3Row6;

// Dolžina zgornjih stringow
uint8_t TITLElenght;
uint8_t Screen1Row1lenght;
uint8_t Screen1Row2lenght;
uint8_t Screen1Row3lenght;
uint8_t Screen1Row4lenght;
uint8_t Screen2Row1lenght;
uint8_t Screen2Row2lenght;
uint8_t Screen2Row3lenght;
uint8_t Screen2Row4lenght;
uint8_t Screen2Row5lenght;
uint8_t Screen2Row6lenght;
uint8_t Screen3Row1lenght;
uint8_t Screen3Row2lenght;
uint8_t Screen3Row3lenght;
uint8_t Screen3Row4lenght;
uint8_t Screen3Row5lenght;
uint8_t Screen3Row6lenght;

// za pomikanje nazaj po menuju
bool m1 = 0;
bool m2 = 0;
bool m3 = 0;

// XBM Bitmap slikice
#define satlogo_h 14
#define satlogo_w 14
static const unsigned char satlogo_bits[] U8X8_PROGMEM = {
    0x00,
    0x18,
    0x00,
    0x3C,
    0x00,
    0x3E,
    0x00,
    0x1F,
    0x60,
    0x0F,
    0xF0,
    0x06,
    0xF0,
    0x01,
    0xE0,
    0x03,
    0xD8,
    0x01,
    0xBC,
    0x2A,
    0x3E,
    0x28,
    0x1F,
    0x16,
    0x0F,
    0x18,
    0x06,
    0x06,
};
#define satlogoz_h 14
#define satlogoz_w 14
static const unsigned char satlogoz_bits[] U8X8_PROGMEM = {
    0x0F,
    0x18,
    0x04,
    0x3C,
    0x02,
    0x3E,
    0x0F,
    0x1F,
    0x60,
    0x0F,
    0xF0,
    0x06,
    0xF0,
    0x01,
    0xE0,
    0x03,
    0xD8,
    0x01,
    0xBC,
    0x2A,
    0x3E,
    0x28,
    0x1F,
    0x16,
    0x0F,
    0x18,
    0x06,
    0x06,
};

// Poziv in dolžina poziva
String page;
uint8_t pagelen;

// Spremenljivke za flipflope in ostalo
int16_t a;
uint16_t selecta;
uint16_t page_select;
int acap;
bool b;
bool c;
bool d;
bool e;
bool f;
bool g;
bool h;
bool fdecl;

/*PROGRAM
    Program je sestavljen iz 24 funkciji. Na začetku sta deklarirane dve perkinitvene
    funkcije ali interrupti, naslednja je funkcija setup() in nakoncu kode je funkcija
    glavne zanke loop(). Vmes so funkcije, ki se izvajajo v glavni zanki.
*/

// Interupti
// Interupt za sprejemanje
void onReceive(int packetSize) {
    MSGstring = LoRa.readString();      //Preberemo sprejet paket
    RSSI = LoRa.packetRssi();           //Preberemo moč paketa
    onRcounter = 1;                     //Nastavimo pomnilno celico na 1
    MSGlenght = MSGstring.length();     //Določimo dolžino niza, ki smo ga sprejeli
    MSG = MSGstring.toInt();            //Niz pretvorimo v naravno število
}

// Interupt za zbujanje in oddajanje
void MENUInterrupt() {
    counter = 1;                        //pomnilno celico nastavimo na 1
}

// Začetna koda, ki initalizira program
void setup() {

    // Initilizacija komunikacije iz UBLOX čipom
    mySerial.begin(38400);              //GNSS serial je nazačetku 9600 in ga je potrebno nastaviti z funkcijo prefliks.setSerialRate(38400);
    myGNSS.begin(mySerial);

    // Initilizacija komunikacije iz čipom za napajanje
    Wire.begin(i2c_sda, i2c_scl);
    axp.begin(Wire, slave_address);
    axp.setChgLEDMode(AXP20X_LED_OFF);      //izključimo ledico, ki signalizira polnjenje


    // Initilizacija oled ekrana
    u8g2.begin();
    u8g2.setFont(u8g2_font_7x13_mf);
    u8g2.setFontMode(0);

    // Initilizacija LoRa čipa
    LoRa.setPins(ss, rst, dio0);

    // Nastavitev IO pinov
    pinMode(tipka1pin, INPUT_PULLDOWN);
    pinMode(tipka3pin, INPUT_PULLDOWN);
    pinMode(piezo, OUTPUT);

    // Koda za prikaz napake v komunikaciji iz LoRo
    if (!LoRa.begin(433E6)) {
        u8g2.clearBuffer();
        u8g2.drawStr(0, 10, "Starting LoRa failed!");
        u8g2.sendBuffer();
        while (1)
            ;
    }

    // LoRa nastavitve
    LoRa.setTxPower(txPower);
    LoRa.setSpreadingFactor(spreadingFactor);
    LoRa.setSignalBandwidth(Bandwidth);
    LoRa.setCodingRate4(codingRateDenominator);
    LoRa.setPreambleLength(preambleLength);

    // Bujenje ESPja in nastavitev interupta
    esp_sleep_enable_ext1_wakeup(BUTTON_PIN_BITMASK, ESP_EXT1_WAKEUP_ANY_HIGH);         //Koda, ki nastavi pine, za zbujanje ESPja
    attachInterrupt(digitalPinToInterrupt(32), MENUInterrupt, RISING);                  //Interrupt za meni

    // LoRa postavitev na sprejem
    LoRa.onReceive(onReceive);          //Interrupt za sprejemanje
    LoRa.receive();

    // Nastavitev GNSSa
    myGNSS.setUART1Output(COM_TYPE_UBX);        //Limitiramo Ublox čipu, da nam podaja podatke samo v obliki UBX
    myGNSS.saveConfiguration();

    // Nastavitev hitrosti procesorja
    setCpuFrequencyMhz(240);

    // Postavitev GNSSa v spanje
    GNSSisOFF = 1;
    if (myGNSS.powerOffWithInterrupt(0, VAL_RXM_PMREQ_WAKEUPSOURCE_UARTRX) == 0) {      //Preverimo, če je od prej Ublox čip še v spanju
        GNSSisOFF = 0;
    }

    // Lil stuff to end idk
    tone(piezo, 4098, 1000);
    u8g2.drawStr(25, 25, "Initialized");
    u8g2.sendBuffer();
    delay(1000);
}
/*FUNKCIJA, KI ŠTEJE, GLEDE NA MILLISE
    Funkcija nam poda novo vrednost pristevnaca, doda jo 1 vsah interval (ms)
*/
uint16_t millisTimeout(uint16_t interval, uint16_t pristevanec) {

    unsigned long currentMillis = millis();
    if (currentMillis - previousTime >= interval) {
        pristevanec++;
        u8g2.sendBuffer();          // Pride prav v vecini primerow
        previousTime = currentMillis;
    }
    return pristevanec;
}
uint16_t millisTimeout1(uint16_t interval, uint16_t pristevanec) {

    unsigned long currentMillis = millis();
    if (currentMillis - previousTime1 >= interval) {
        pristevanec++;
        u8g2.sendBuffer();
        previousTime1 = currentMillis;
    }
    return pristevanec;
}

/*Funkcija za prekinitev zank, če je negdo pritisnil tipko ali v primeru
 sprejetja paketa.
 0 za counter (MENU), 1 za onRcounter(sprejem)
*/
void check(bool interupt_stevec) {
    if (interupt_stevec == 0) {
        if (counter == 1) {
            m1 = 1;
            m2 = 1;
            m3 = 1;
            whilecounter = timeouttime;
        }
    }
    if (interupt_stevec == 1) {
        if (onRcounter == 1) {
            whilecounter = timeouttime;
            m1 = 1;
            m2 = 1;
            m3 = 1;
        }
    }
}

/*Funkcija za poenostavljanje spremenljivk
 x >> 0 za poenostavitev števcev, 1 za poenastavitev spremenljivk
 Delay >> Koliko delaya dodamo za debounce*/
void reset(bool x, uint16_t Delay) {

    delay(Delay);
    if (x == 1) {
        TITLE = "";         // Zaradi določanja dolžine in ustavljanja v level funkciji
        Screen1Row1 = "";
        Screen1Row2 = "";
        Screen1Row3 = "";
        Screen1Row4 = "";
        Screen2Row1 = "";
        Screen2Row2 = "";
        Screen2Row3 = "";
        Screen2Row4 = "";
        Screen2Row5 = "";
        Screen2Row6 = "";
        Screen3Row1 = "";
        Screen3Row2 = "";
        Screen3Row3 = "";
        Screen3Row4 = "";
        Screen3Row5 = "";
        Screen3Row6 = "";

        a = 0;
        b = 0;
        c = 0;
        d = 0;
        e = 0;
        f = 0;
        g = 0;
        h = 0;
        selecta = 1;
        page_select = 0;
    }
    if (x == 0) {
        counter = 0;
        onRcounter = 0;
        whilecounter = 0;
    }
}

/*GNSS parser je funkcija, ki iz pomočjo zaporedji sestevi besedo iz podatkov in jo poslje,
    ali sprejme in raztavi na uporabne elemente.
    Recieved >> 1 če raztavljamo oz smo sprejeli GNSS, 0 če pošiljamo GNSS
    latitude >> damo podatek iz gnssja
    longitude >> damo podatek iz gnssja
    altitude >> damo podatek iz gnssja
    returntype >> kateri podatek bomo dobivali, če sprejemamo 1>latitude 2>longitude 3>altitude
    Za uspešno sprejet funkcija vrne 10, če karkoli gre narobe pa 0.
*/
float LoRa_GNSS_Parser(bool recieved, uint32_t latitude, uint32_t longitude, uint32_t altitude, uint8_t returntype) {
    char buffer[32];
    char recievedbuffer[32];

    int32_t Slat = 0;
    int32_t Slon = 0;
    int32_t Salt = 0;

    float gpsfloatLAT;
    float gpsfloatLON;
    float gpsfloatALT;

    String StringToSend = "";

    if (recieved == 0) {
        sprintf(buffer, "%d %d %d", latitude, longitude, altitude);     //Zapakiramo v zbirko
        StringToSend = String(buffer);                      //Spremenimo array v niz
        LoRa.beginPacket();
        LoRa.print(StringToSend);
        LoRa.endPacket(true);           //Pošljemo paket brez zahteve za stabilno povezavo
        delay(4000);
        LoRa.receive();
        return 10;
    }
    if ((recieved == 1) && (MSGlenght > 5)) {
        MSGstring.toCharArray(recievedbuffer, 32);              //Sprejeti niz pretvorimo v zbirko
        sscanf(recievedbuffer, "%d %d %d", &Slat, &Slon, &Salt);        //Raztavimo zbirko

        gpsfloatLAT = Slat / 10000000.;
        gpsfloatLON = Slon / 10000000.;
        gpsfloatALT = Salt / 1000.;

        if (returntype == 1) {
            return gpsfloatLAT;
        }
        if (returntype == 2) {
            return gpsfloatLON;
        }
        if (returntype == 3) {
            return gpsfloatALT;
        }
    }
    return 0;
}

/*Funcije za display in pisanje na display:
Nize, ki jih hočemo prikazati na OLEDU navajamo kot Screen1Row1 = "";
Priporočeno je pred to funkcijo klicati tudi reset funkcijo.
*/
void astop(uint8_t x) {     //Za določanje gdaj se ustavi kazalec
    if (x > 1) {
        acap += 10;
    }
}

void level() {
    TITLElenght = TITLE.length();           //Določimo dolžine vseh nizov
    Screen1Row1lenght = Screen1Row1.length();
    Screen1Row2lenght = Screen1Row2.length();
    Screen1Row3lenght = Screen1Row3.length();
    Screen1Row4lenght = Screen1Row4.length();
    Screen2Row1lenght = Screen2Row1.length();
    Screen2Row2lenght = Screen2Row2.length();
    Screen2Row3lenght = Screen2Row3.length();
    Screen2Row4lenght = Screen2Row4.length();
    Screen2Row5lenght = Screen2Row5.length();
    Screen2Row6lenght = Screen2Row6.length();
    Screen3Row1lenght = Screen3Row1.length();
    Screen3Row2lenght = Screen3Row2.length();
    Screen3Row3lenght = Screen3Row3.length();
    Screen3Row4lenght = Screen3Row4.length();
    Screen3Row5lenght = Screen3Row5.length();
    Screen3Row6lenght = Screen3Row6.length();

    astop(Screen1Row1lenght);       //Določimo gdaj se ustavi
    astop(Screen1Row2lenght);
    astop(Screen1Row3lenght);
    astop(Screen1Row4lenght);
    astop(Screen2Row1lenght);
    astop(Screen2Row2lenght);
    astop(Screen2Row3lenght);
    astop(Screen2Row4lenght);
    astop(Screen2Row5lenght);
    astop(Screen2Row6lenght);
    astop(Screen3Row1lenght);
    astop(Screen3Row2lenght);
    astop(Screen3Row3lenght);
    astop(Screen3Row4lenght);
    astop(Screen3Row5lenght);
    astop(Screen3Row6lenght);

    if (a < 0) {
        u8g2.clearBuffer();
        a = acap - 10;
        selecta = (acap - 10) / 10 + 1;
    }

    if ((a < 35) && (d == 1)) {
        u8g2.clearBuffer();
    }

    if ((a < 95) && (e == 1)) {
        u8g2.clearBuffer();
    }

    if ((a < 35) || (Screen2Row1lenght < 1)) {  //Prva stran

        if (a > (acap - 10)) {
            a = 0;
            selecta = 1;
            f = 1;
            u8g2.clearBuffer();
        }

        u8g2.setFont(u8g2_font_7x13_mf);            
        u8g2.setCursor((128 - (TITLElenght)*7) / 2, 12);        //Izpišemo na ekran
        u8g2.print(TITLE);
        u8g2.setFont(u8g2_font_6x10_mf);
        u8g2.setCursor((128 - (Screen1Row1lenght)*6) / 2, 30);
        u8g2.print(Screen1Row1);
        u8g2.setCursor((128 - (Screen1Row2lenght)*6) / 2, 40);
        u8g2.print(Screen1Row2);
        u8g2.setCursor((128 - (Screen1Row3lenght)*6) / 2, 50);
        u8g2.print(Screen1Row3);
        u8g2.setCursor((128 - (Screen1Row4lenght)*6) / 2, 60);
        u8g2.print(Screen1Row4);

        if (a > 5) {
            u8g2.drawStr(0, 20 + a, " ");
            u8g2.drawStr(120, 20 + a, " ");
        }

        u8g2.drawLine(0, 16, 128, 16);

        if (((a < 25) && (Screen2Row1lenght > 0)) || (Screen2Row1lenght == 0)) {    //Kazalci
            u8g2.drawStr(0, 30 + a, ">");
            u8g2.drawStr(120, 30 + a, "<");
        }
        if ((Screen2Row1lenght > 0) && (a > 25)) {
            u8g2.drawStr(0, 30 + a, "v");
            u8g2.drawStr(120, 30 + a, "v");
        }

        u8g2.drawStr(0, 40 + a, " ");
        u8g2.drawStr(120, 40 + a, " ");

        d = 0;
    }

    if ((digitalRead(tipka3pin) == 1) && (b == 0)) {    //Preberemo ali je tipka pritisnjena in če je izvršimo premik
        a += 10;
        whilecounter = 0;
        b = 1;
        selecta++;
    }
    if (digitalRead(tipka3pin) == 0) {
        b = 0;
    }
    if ((digitalRead(tipka1pin) == 1) && (c == 0)) {
        a -= 10;
        whilecounter = 0;
        c = 1;
        selecta--;
    }
    if (digitalRead(tipka1pin) == 0) {
        c = 0;
    }

    if ((a > 35) && (d == 0) && (Screen2Row1lenght > 1)) {
        u8g2.clearBuffer();
    }

    if ((a > 95) && (e == 0)) {
        u8g2.clearBuffer();
    }

    if (f == 1) {
        u8g2.drawStr(0, 60, " ");
        u8g2.drawStr(120, 60, " ");
        f = 0;
    }

    if (((a > 35) && (Screen2Row1lenght > 1) && (a < 95)) || ((Screen3Row1lenght < 1) && (d == 1))) {       //Druga stran

        if (a > (acap - 10)) {
            a = 0;
            selecta = 1;
            f = 1;
        }

        u8g2.setFont(u8g2_font_6x10_mf);
        u8g2.setCursor((128 - (Screen2Row1lenght)*6) / 2, 10);      //Izpišemo na ekran
        u8g2.print(Screen2Row1);
        u8g2.setCursor((128 - (Screen2Row2lenght)*6) / 2, 20);
        u8g2.print(Screen2Row2);
        u8g2.setCursor((128 - (Screen2Row3lenght)*6) / 2, 30);
        u8g2.print(Screen2Row3);
        u8g2.setCursor((128 - (Screen2Row4lenght)*6) / 2, 40);
        u8g2.print(Screen2Row4);
        u8g2.setCursor((128 - (Screen2Row5lenght)*6) / 2, 50);
        u8g2.print(Screen2Row5);
        u8g2.setCursor((128 - (Screen2Row6lenght)*6) / 2, 60);
        u8g2.print(Screen2Row6);

        u8g2.drawStr(0, -40 + a, " ");
        u8g2.drawStr(120, -40 + a, " ");

        if (((a < 85) && (Screen3Row1lenght > 0)) || ((Screen3Row1lenght == 0) && (a > 45))) {      //Kazalec
            u8g2.drawStr(0, -30 + a, ">");
            u8g2.drawStr(120, -30 + a, "<");
        }
        if ((Screen3Row1lenght > 0) && (a > 85)) {
            u8g2.drawStr(0, -30 + a, "v");
            u8g2.drawStr(120, -30 + a, "v");
            u8g2.drawStr(0, 10, " ");
            u8g2.drawStr(120, 10, " ");
        }
        if (a < 45) {
            u8g2.drawStr(0, -30 + a, "^");
            u8g2.drawStr(120, -30 + a, "^");
        }

        u8g2.drawStr(0, -20 + a, " ");
        u8g2.drawStr(120, -20 + a, " ");
        d = 1;
        e = 0;
    }

    if ((a > 95) && (Screen3Row1lenght > 1)) {      //Tretja stran

        if (a > (acap - 10)) {
            a = 0;
            selecta = 1;
            f = 1;
        }

        u8g2.setFont(u8g2_font_6x10_mf);
        u8g2.setCursor((128 - (Screen3Row1lenght)*6) / 2, 10);      //Izpišemo
        u8g2.print(Screen3Row1);
        u8g2.setCursor((128 - (Screen3Row2lenght)*6) / 2, 20);
        u8g2.print(Screen3Row2);
        u8g2.setCursor((128 - (Screen3Row3lenght)*6) / 2, 30);
        u8g2.print(Screen3Row3);
        u8g2.setCursor((128 - (Screen3Row4lenght)*6) / 2, 40);
        u8g2.print(Screen3Row4);
        u8g2.setCursor((128 - (Screen3Row5lenght)*6) / 2, 50);
        u8g2.print(Screen3Row5);
        u8g2.setCursor((128 - (Screen3Row6lenght)*6) / 2, 60);
        u8g2.print(Screen3Row6);

        u8g2.drawStr(0, -100 + a, " ");
        u8g2.drawStr(120, -100 + a, " ");

        if (a > 105) {
            u8g2.drawStr(0, -90 + a, ">");      //Kazalec
            u8g2.drawStr(120, -90 + a, "<");
        }
        if (a < 105) {
            u8g2.drawStr(0, -90 + a, "^");
            u8g2.drawStr(120, -90 + a, "^");
        }

        u8g2.drawStr(0, -80 + a, " ");
        u8g2.drawStr(120, -80 + a, " ");
        e = 1;
    }
    acap = 0;
    u8g2.setFont(u8g2_font_7x13_mf);
    u8g2.sendBuffer();                  //Pošjemo na ekran
}
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
void loop() {
    u8g2.setPowerSave(0);
    u8g2.clearDisplay();
    u8g2.clearBuffer();
    delay(500);

    while ((counter != 0) || (onRcounter != 0)) {       //Preverimo gdo je zbudil ESP, a smo sprejeli poziv ali pritisnili tipko
        if ((counter == 1) && (onRcounter == 0)) {      //Se izvrši če smo prritisnili tipko
            fdecl = 1;
            menu();
        } else if ((counter == 0) && (onRcounter == 1)) {   //V drugem primeru se izvrši ta, če smo sprejeli poziv
            reset(0, 100);
            fdecl = 0;
            if (MSGlenght > 5) {
                while (whilecounter < timeouttime) {
                    whilecounter = millisTimeout(1000, whilecounter);

                    if ((whilecounter % 2) == 0) {
                        tone(piezo, 4000, 250);
                    }
                    u8g2.clearBuffer();
                    u8g2.setFont(u8g2_font_7x13_mf);
                    u8g2.drawStr(0, 10, "RECIEVING GPS");   //Izpišemo GNSS podatke, če smo jih sprejeli.
                    u8g2.setFont(u8g2_font_6x10_mf);
                    u8g2.drawStr(0, 30, "LAT:");
                    u8g2.drawStr(0, 40, "LON:");
                    u8g2.drawStr(0, 50, "ALT:");
                    u8g2.drawStr(0, 60, "RSSI:");
                    u8g2.setCursor(25, 30);
                    u8g2.print(LoRa_GNSS_Parser(1, 0, 0, 0, 1), 5);
                    u8g2.setCursor(25, 40);
                    u8g2.print(LoRa_GNSS_Parser(1, 0, 0, 0, 2), 5);
                    u8g2.setCursor(25, 50);
                    u8g2.print(LoRa_GNSS_Parser(1, 0, 0, 0, 3), 5);
                    u8g2.setCursor(32, 60);
                    u8g2.print(RSSI);
                }
            }
            u8g2.clearBuffer();
            pages(MSG);
            reset(0, 100);
        }
    }

    u8g2.clearDisplay();
    u8g2.clearBuffer();
    u8g2.setPowerSave(1);
    if ((GNSSisOFF == 0) && (GNSSsleepSETTIING != 3)) {
        myGNSS.powerOffWithInterrupt(0, VAL_RXM_PMREQ_WAKEUPSOURCE_UARTRX);     //Damo GNSS čip v spanje, če ni v spanju
        GNSSisOFF = 1;
    }
    delay(100);
    esp_light_sleep_start();    //Začnemo lahko esp32 spanje. Naša poraba na sprejemu nam pade na 16mA
}
